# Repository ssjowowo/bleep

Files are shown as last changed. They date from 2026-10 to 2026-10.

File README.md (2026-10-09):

# Bleep

**A DIY touchscreen universal remote.** It's built around an ESP32-S3 on a main board of our own, with a 3.5″ IPS touch display, 14 physical keys, IR send and learn, haptics, and Home Assistant control over Wi-Fi. The case is 3D-printed and only 13 mm thick.

<p align="center">
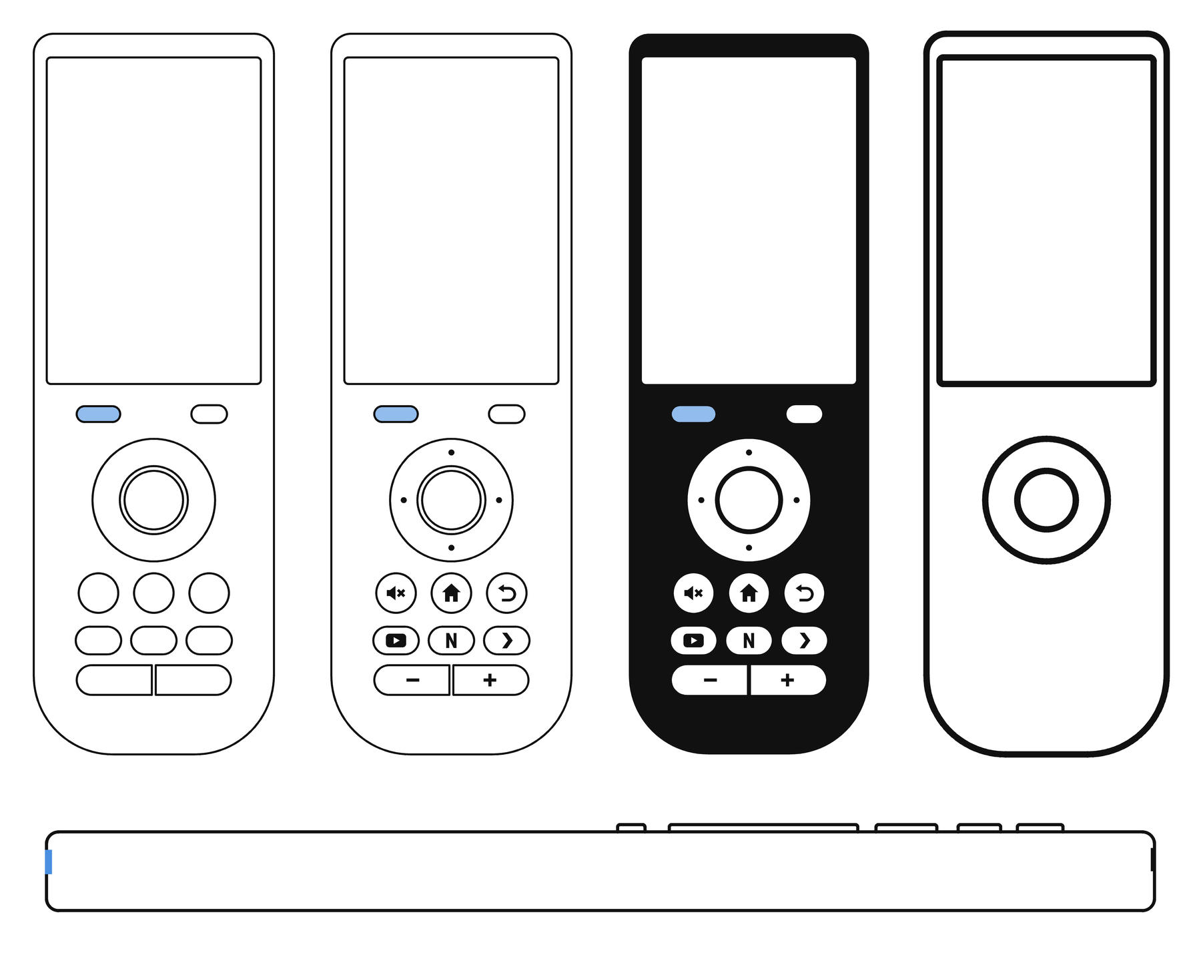
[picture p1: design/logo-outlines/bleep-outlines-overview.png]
Bleep front outlines in four styles and a side profile
  
  &nbsp;
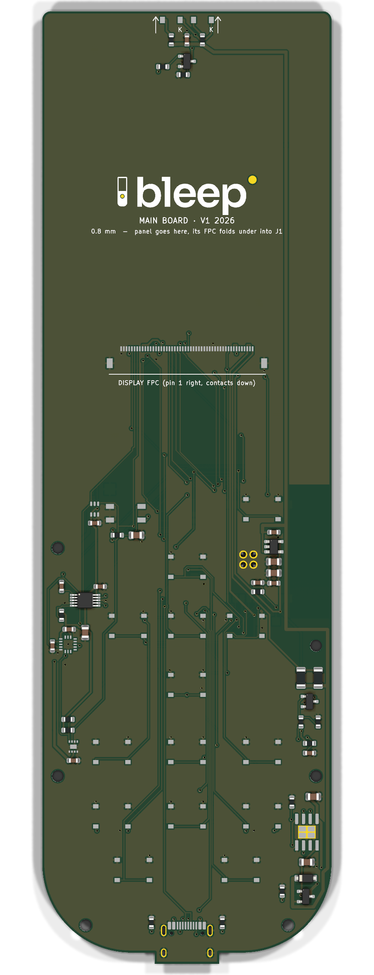
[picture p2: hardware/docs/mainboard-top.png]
Render of the Bleep v1 main board, top side
  
</p>

## What it is

Most universal remotes either have a screen and few buttons, or lots of buttons and no screen. Bleep has both. The touchscreen shows activities, now-playing and smart-home controls. The keys you use without looking stay physical: a D-pad ring with OK, Back, Home, Mute, three app keys (YouTube, Netflix, Plex) and a volume rocker.

- **IR out**: two side-view 940 nm IR LEDs at the top end control TVs, receivers and boxes.
- **IR learning**: a 38 kHz receiver behind a small window under the screen copies codes from your old remotes.
- **Wi-Fi**: Home Assistant control of lights, scenes and media through the ESP32-S3.
- **Feel**: a coin vibration motor driven by a DRV2605L haptics driver.
- **Smart power**: lift-to-wake (accelerometer), wake on touch or any key, auto-brightness (light sensor), and a fuel gauge for an accurate battery percentage. Asleep it draws about 0.1–0.15 mA, so a charge lasts months.
- **USB-C** for charging and flashing.

The hardware is designed for all of this. The firmware's app and UI run today in an emulator (on the PC or in a browser) while the boards are being made; the ESP32-S3 port comes when they arrive. See [firmware/README.md](firmware/README.md).

The industrial design comes from a concept pack made in Claude Design (design **1b "Pebble"**, in `design/`). The brand (wordmark, logo lockup) comes from the Bleep brand book.

## Status

| Part | State |
|---|---|
| Main board v1 | **Ordered** from JLCPCB on 2026-10-08 (5 boards, 2 assembled). The design is locked: the files in `hardware/mainboard/` are the ones in production. |
| Enclosure | Ready to print. The back plate is flat, with room for a 4.0 × 50 × 85 mm Li-Po (405085) under the screen. |
| Display | BuyDisplay ER-TFT035IPS-6 + capacitive touch, **ordered** 2026-10-09. Its cable fold gets checked on the real panel before assembly. |
| Battery | **Ordered** 2026-10-09 (405085 planned; if the cell differs, set `BATT` in `layout.py` and rebuild the back plate). |
| Firmware | App and UI (C + LVGL 9) running in a PC/browser emulator with 32 scripted test scenarios; ESP-IDF port next. [firmware/](firmware/) |

## Hardware at a glance

| | |
|---|---|
| Size | 60.7 × 182.2 × 13.0 mm |
| MCU | ESP32-S3-WROOM-1-N8R2 (8 MB flash, 2 MB PSRAM), antenna at the right edge beside the D-pad |
| Display | 3.5″ IPS 320 × 480, ILI9488 on an 8-bit parallel bus (much faster than SPI), FT6236 capacitive touch |
| Keys | 14 tactile switches, each on its own wake-capable GPIO |
| IR | 2 × VSMB2948SL LEDs (≈ 125 mA peaks), IRM-H638T receiver for learning |
| Sensors | MMA8452Q accelerometer, LTR-303ALS light sensor, MAX17048 fuel gauge |
| Power | 1-cell Li-Po, TP4056 charger with load sharing, ME6211 3.3 V LDO |
| Board | 2 layers, 0.8 mm, 54 × 178 mm. JLCPCB assembles the top side; you solder the ESP32 module, battery and motor on the underside. |
| Case | PETG, two colours for the key labels (flush inlays), plus translucent blue PETG for the IR and sensor windows (two small separate prints); the board screwed to the front shell (4 × M2×4) and the back plate held by 2 × M2×8 and two snap fingers, all into heat-set inserts |

The parts list, pin map, assembly steps, ordering guide (≈ €130 in total, delivered to Cyprus) and firmware notes are in **[hardware/README.md](hardware/README.md)**.

## How it's built

Everything mechanical comes from one file, [`hardware/layout.py`](hardware/layout.py). It holds the display and part sizes, the key layout, where each part sits, the z stack and the screw points, and it runs fit checks on all of them. Two generators read it:

- **Enclosure**: `layout.py` writes `enclosure/params.scad`, and [`enclosure/remote.scad`](hardware/enclosure/remote.scad) (OpenSCAD) builds the front shell, its two windows, back plate, key caps and label inlays as STLs, plus interference checks.
- **Main board**: [`mainboard/gen_mainboard.py`](hardware/mainboard/gen_mainboard.py) places the parts in KiCad 10 from the same numbers. [Freerouting](https://github.com/freerouting/freerouting) routes it, then the generator adds ground pours, runs DRC and exports Gerbers, BOM and CPL for JLCPCB.

The board and the case can't drift apart. Since the board was ordered, `layout.py` checks every value the board was built from against `mainboard/pcb_lock.json`. It refuses to run if a case change would move one of them.

## Repository layout

```
design/              concept pack (open the .dc.html files in a browser), brand assets, outline drawings
hardware/
  layout.py          the single source of truth for the mechanics
  build.sh           rebuilds everything from layout.py
  enclosure/         OpenSCAD source and the printable STLs (enclosure/stl/)
  mainboard/         KiCad board, generator, routing logs; fab/ = Gerbers, BOM, CPL (locked)
  viewer/            3D colour viewer (three.js) for trying colourways
  docs/              datasheets and renders
HANDOFF.md           current working state, for picking the project up on another machine
```

## Building

```bash
cd hardware
./build.sh enclosure   # STLs, renders and fit checks
./build.sh viewer      # meshes for the 3D viewer (viewer/index.html)
```

You need Python 3 (no extra packages) and OpenSCAD 2021.01 or newer, on the PATH or set with `OPENSCAD=`. The board rebuild (`./build.sh pcb`) also needs KiCad 10 and Freerouting, and it's disabled while v1 is locked.

To open the 3D viewer locally, run `python3 -m http.server -d hardware/viewer 8742` and go to <http://localhost:8742>.

## Roadmap

1. Boards and display arrive: check the display cable fold, solder the underside parts, print the case.
2. Firmware: LVGL UI (activities, now playing, Home Assistant), IR send and learning through the RMT peripheral, deep sleep with key, touch and lift wake.
3. Fixes found on the real hardware go into a v2 board.

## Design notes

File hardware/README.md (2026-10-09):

# Bleep v1 — hardware (own ESP32 + plug-in display)

**One main board of our own** with a **3.5" IPS panel with capacitive touch (BuyDisplay ER-TFT035IPS-6)** lying flat on it, plugged into a connector on the board. The keypad has a ring D-pad. The shell is slim: only wall and clearance beside the glass, the glass 4.8 mm from the top end (5 mm top corners), and the power key and sensor window in a row under the screen.

| | |
|---|---|
| Size | 60.7 × 182.2 × **13.0 mm** |
| Display | BuyDisplay ER-TFT035IPS-6 (ILI9488) + ER-TPC035-6 touch (FT6236), 3.75 mm, one 50-pin FPC |
| ESP32 | ESP32-S3-WROOM-1-N8R2 module (8 MB flash, 2 MB PSRAM) |
| Battery | flat Li-Po up to 4.0 mm thick and 50.8 × 86.1 mm (sized for a 405085), under the screen |
| You solder | ESP32 module, battery, vibration motor (the display just plugs in) |

Everything is generated from [`layout.py`](layout.py):

```bash
./build.sh            # everything: STLs, renders, PCB, viewer meshes
./build.sh enclosure  # STLs + renders + fit checks
./build.sh pcb        # main board: place, route, DRC, Gerbers, BOM/CPL
```

It needs Python 3 (no extra packages) and OpenSCAD 2021.01+, found on the PATH or set with `OPENSCAD=`. The PNG renders in `docs/` need a display, so on a headless Linux box they're skipped.

## Stack (from the back face, 4 mm cell)

| z (mm) | |
|---|---|
| 0 – 1.5 | back plate |
| 1.5 – 6.0 | open space: battery (+0.5 swell gap) under the screen; ESP32 module, vibration motor and the heads of the 4 board screws under the keys. The back plate is flat; the board rests on rails along its edges under the screen, a standoff at each of the plate's 2 screws and a 3 mm pillar under each key switch |
| 6.0 – 6.8 | main board, 0.8 mm |
| 6.8 – 8.4 | under the LCD: the 50-pin ZIF connector (1.5 mm), the folded display FPC and its parts area, foam pads at the top end |
| 8.4 – 12.15 | LCD (2.1) + touch glass (1.65) |
| 12.15 – 12.95 | front frame over the glass edge |

The cell thickness sets H: 3 mm → 12.0, 4 mm → 13.0, 5 mm → 14.0 mm. Change `BATT` in `layout.py` and rebuild.

## Main board

> **Locked (2026-10-08).** Bleep v1's main board is ordered from JLCPCB: 5 boards, green mask, HASL, Economic assembly of 2. `mainboard/mainboard.kicad_pcb` and `mainboard/fab/` are the ordered files and are read-only. `./build.sh` no longer touches the board, and `./build.sh pcb` refuses. Only the shell and the firmware change from here. `layout.py` stops with "PCB LOCKED" if a shell change would move anything the board was built from: part positions, keys, holes, outline, antenna keep-out, GPIO map. The record is in `mainboard/pcb_lock.json`.

Status (2026-10-08, slim version, after an independent review): fully routed, KiCad DRC **0 violations, 0 unconnected**; Gerbers, BOM and CPL in `mainboard/fab/`. The CPL rotations are checked against JLCPCB's own footprints for every part. Renders: [top](docs/mainboard-top.png), [underside](docs/mainboard-bottom.png).

Branding follows the Bleep Brand Book (PCB section): the logo lockup in one-colour silk, large on the back (40 mm, under the battery) and smaller on the front (26 mm, under the panel), each with the board ID `MAIN BOARD · V1 2026`. The display and the ring round the LED are knocked out of the silk, and both LED dots are bare copper pads. They come out gold with ENIG; with the HASL finish in the current order they're silver tin. The brand book also calls for a matte black solder mask; colour and finish are order options, not changes to the files. The lockup is built in `mainboard/logo.py` from the brand book's mark and a trace of the wordmark (`../design/brand/`); `gen_mainboard.py rebrand` re-applies it to the routed board without re-routing.

Routing: [Freerouting](https://github.com/freerouting/freerouting) 2.5 does it, about 5 minutes for `./build.sh pcb`. A few things are drawn by hand first and passed to it as fixed copper: the VSYS rail (charger → right edge → LDO → up the right side to the IR LEDs), the LDO's pins and the 3V3 run to the module, the vibration-motor wires (on the bottom layer) and the USB D+/D− crossing. VBAT and VSYS are 0.5–0.6 mm wide (the cell → LDO path carries the Wi-Fi bursts: ≈ 0.2 Ω end to end, about 0.1 V at 500 mA), the other power nets 0.3 mm, and Freerouting may not put vias in SMD pads. GND is a pour on both layers; after routing, `gen_mainboard.py fab` stitches any pour piece the tracks cut off back to the main ground with a via. Freerouting needs a Java 25 runtime; `build.sh` looks for it and the jar in `%LOCALAPPDATA%\freerouting\`, and its settings file (`%APPDATA%\freerouting\freerouting.json`) has automatic neck-down off, so no track goes below 0.15 mm. The older grid router (`mainboard/route.py`) is still there but couldn't route this layout.

| Part | Where | Notes |
|---|---|---|
| 14 key switches (TS-1187A) | top, JLCPCB | each straight to an ESP32 RTC GPIO, so any key wakes it |
| USB-C | top, bottom edge | 5.1 k CC pull-downs, D+/D− to the ESP32's native USB (flashing + serial) |
| TP4056 charger | top, right strip, near USB-C | 360 mA (PROG 3.3 k); CHRG/STDBY to GPIO12/3 |
| Load sharing (AO3401A + B5819W + 100 k) | top, under the charger | on USB the remote runs from VBUS and the charger sees only the cell, so it terminates properly; off USB the cell feeds the system through the P-MOSFET |
| ME6211 3.3 V LDO | top, over the module by its 3V3 pin | 500 mA, from VSYS (the cell, or USB when plugged in) |
| DRV2605L + MMA8452Q | top, left strip | haptics (always enabled, standby over I²C); accelerometer for lift-to-wake (INT1 → GPIO2, transient/motion interrupt) |
| 2 × VSMB2948SL IR LEDs | top edge, centred; their driver sits under the LCD | 22 Ω each from VSYS (≈ 125 mA peaks at 4.2 V), one AO3400A; silk arrows mark the lens direction |
| Backlight driver | top, right strip | LED+ from VSYS via 2 × 22 Ω (1206, they see up to ≈ 0.12 W each on USB), cathodes switched by an AO3400A on GPIO46 (PWM) |
| 50-pin 0.5 mm ZIF connector (XUNPU FPC-05F-50PH15) | top, under the panel, JLCPCB | bottom contact, flip lid; the display FPC folds under and plugs in |
| ESP32-S3-WROOM-1-N8R2 | **underside**, across the board just below the screen | **you solder**. It must be the **N8R2**: the N8R8 (octal PSRAM) uses GPIO35–37, which are LCD D0–D2 here; antenna at the **right edge**, beside the D-pad, with no copper on either layer around it (3.5 mm past the module's sides). It can't go under the screen: the panel would detune it. |
| IR receiver (Everlight IRM-H638T, 38 kHz) | in the row under the screen, left, under the sensor window (3.0 mm hole) | for **learning** codes from existing remotes; output on GPIO42. Powered from GPIO1 through 220 Ω + 10 µF, so it's only on while learning (it draws 0.4 mA) |
| Ambient light sensor (LTR-303ALS-01) | beside the IR receiver, same window (1.6 mm hole, with a translucent PETG light pipe down to it) | auto-brightness; I²C `0x29` |
| Fuel gauge (MAX17048) | top, left strip | battery %, time-to-empty and the cell voltage; I²C `0x36` |
| EN + GND reset pads | underside, below the module, under a slot in the back plate | short them (a small screwdriver across both) to reset the ESP32 without opening the case |
| BAT+ / BAT− pads, vibration-motor pads | underside: battery pads just below the screen on the left, motor in the left strip | the motor is an 8 mm ERM (or LRA) coin, set in firmware |

### ESP32-S3 pin map

| GPIO | Use | GPIO | Use |
|---|---|---|---|
| 0 | OK key (hold at reset = download mode) | 21 | LCD D/C |
| 1 | IR receiver power (high while learning) | 35 – 41 | LCD D0 – D6 |
| 2 | MMA8452Q INT1 (lift-to-wake) | 42 | IR receiver output (learning) |
| 3 | charger STDBY | 43 | LCD D7 |
| 4, 5, 6, 7 | UP, RIGHT, LEFT, DOWN | 44 | LCD WR |
| 8, 9 | NFLX, YT | 45 | IR LED (pulled low) |
| 10, 11 | VOL+, VOL− | 46 | backlight PWM (pulled low) |
| 12 | charger CHRG | 47, 48 | I²C SDA / SCL |
| 13, 14 | PWR key / touch INT | 19, 20 | USB D− / D+ |
| 15, 16, 17, 18 | BACK, HOME, MUTE, PLEX | | |

I²C: FT6236 touch `0x38`, DRV2605L `0x5A`, MMA8452Q `0x1C`, LTR-303ALS `0x29`, MAX17048 `0x36`. The LCD and touch controller share an RC power-on reset (10 k × 1 µF), so after power-up the firmware resets the ILI9488 with its software-reset command (0x01). Display: ILI9488 on the ESP32-S3's i80 LCD bus, **8080 8-bit parallel** (IM2–IM0 = 011, CS tied low, RD tied high), 320 × 480. That's several times faster than the ILI9488's SPI mode, which only takes 18-bit colour. GPIO43/44 are UART0, so use the USB-Serial/JTAG console in firmware; the ROM's boot messages on GPIO43 are harmless because WR stays high. Every GPIO is used.

## Display

**BuyDisplay ER-TFT035IPS-6** — 3.5" IPS, 320 × 480, ILI9488, LCD 54.56 × 82.84 × 2.1 mm — with the **ER-TPC035-6** capacitive touch panel (FT6236, glass 56.54 × 84.96 mm, 3.75 mm in total). Backlight ≈ 3.0–3.3 V at 120 mA. One 50-pin 0.5 mm FPC, 30 mm long, carries the LCD and the touch I²C. The datasheet, touch drawing and connector drawing are in `docs/`; the old QD3525 papers are in `docs/old-qd3525/`.

The FPC leaves the panel's bottom edge, makes a U-bend down past the glass and runs 24 mm back under the LCD into the ZIF connector J1. That puts the FPC's pin 1 on the right, seen from the front; the board's silk says so. The FPC's small parts area (≤ 1.5 mm) also lies under the LCD.

## Assembly order

1. **ESP32 module** (underside, lying across the board below the screen, antenna end at the right edge as the silk shows): tack two corners, then solder the edge pads. Solder the centre GND pad from the top side: feed solder into its four 1 mm holes until each one fills (the module's pad heats slowly, so use a hot, broad tip). Pins 1 and 40 (GND, by the antenna) are also tied to that pad with tracks.
2. **Battery** leads to BAT+ / BAT− (underside, just below the screen on the left), **motor** leads to its pads (red to +). Cut the battery's plug off and solder the leads straight to the pads, red to BAT+: at 4 mm there's no room for a connector. Stick the motor to the board's underside by its adhesive back, on its spot in the left strip. The cell goes at the top end, under the screen and as far from the antenna as it goes, between the four corner guides on the back plate; its leads run down to the pads. A piece of Kapton tape on the board's underside over the cell area keeps via tips off the pouch.
3. **Display**: lay the panel face down beyond the board's key end, FPC towards J1. Flip J1's lid up, slide the FPC in with its contacts facing the board, then close the lid. Fold the panel over onto foam pads (two layers of 1 mm foam tape) at the board's top end, so the FPC makes a U-bend under it. Stick the pads left and right of the small IR-driver parts there (they sit under the LCD now), not on them.
4. Flash over USB-C. esptool resets the ESP32 into download mode over USB by itself. If a broken firmware stops that from working, hold OK and short the two reset pads through the slot in the back plate (a small flat screwdriver across both), then release them while still holding OK. Plugging in USB doesn't reset the ESP32 once the battery is connected.
5. Key caps into the front shell, face down: the **OK** button first, then the one-piece **D-pad ring** over it (the ring holds the OK in), then the other caps.
6. Board into the front shell (glass into its pocket), then screw it to the four posts in the key area with **4 × M2×4** from its underside, into the inserts. Use nylon screws, or at least put a disc of Kapton tape under the head at the top-left hole (H1): a VBAT track passes 1.75 mm from its centre on the underside, under the edge of a 4 mm head, with only solder mask in between.
7. Battery on the back plate between its corner guides. Hook the back plate's top end in first: its two snap fingers click into grooves in the top wall. Then close it with **2 × M2×8** through the bottom bosses (they pass through the board too).

## Ordering

Prices checked 2026-10-07, delivered to Cyprus. Every AliExpress line adds about €3 of EU import charges.

### 1. JLCPCB: PCB + assembly, plus LCSC in the same parcel

Before paying, open J1 in the Component Placements 3D view: its flip lid and opening must face the bottom of the board (towards the keys), where the folded cable comes from. Upload `mainboard/fab/mainboard-gerbers.zip`, then PCB Assembly with `mainboard-BOM.csv` and `mainboard-CPL.csv`. PCB: 2 layers, **0.8 mm**, HASL, qty 5. Assembly: **Economic**, top side, qty 2. Order remark for the IR LEDs: *"D1/D2 VSMB2948SL side-view IR LEDs: lens faces the board's top edge (silk arrows), cathode = pad marked K."*

| JLCPCB item | US$ |
|---|---|
| 5 PCBs, 2 layers, 0.8 mm, 54 × 178 mm | ≈ 9.40 |
| Economic assembly setup + stencil | ≈ 9.71 |
| 10 Extended parts × $3.07 (USB-C, TP4056, ME6211, DRV2605L, MMA8452Q, IR LED, ZIF connector, IR receiver, light sensor, fuel gauge) | 30.70 |
| Parts for 2 boards (DRV2605L $1.58, MMA8452Q $1.57, MAX17048 $1.31, IR LED $0.45, LTR-303ALS $0.27, ZIF $0.21, IR receiver $0.13, TP4056 $0.18, AO3400A $0.09, USB-C $0.07, ME6211 $0.06, switches $0.02 …) | ≈ 15.00 |
| Solder joints | ≈ 1.20 |
| **JLCPCB subtotal** | **≈ 66** |

Then at [LCSC](https://www.lcsc.com/) add these and choose "Combine your LCSC and JLCPCB orders" at checkout (one parcel, one shipping fee):

| Part | LCSC | Qty | US$ |
|---|---|---|---|
| ESP32-S3-WROOM-1-N8R2 | [C2913204](https://www.lcsc.com/product-detail/C2913204.html) | 2 (one spare) | 9.36 |
| M2 × 3 × 3.2 brass heat-set insert | [C51938982](https://www.lcsc.com/product-detail/C51938982.html) | 50 (minimum) | 0.50 |

Shipping ≈ $11 (Global Standard, 12–19 days). VAT is added at checkout.

### 2. BuyDisplay: the display

[3.5" IPS 320×480 TFT with capacitive touch](https://www.buydisplay.com/3-5-inch-ips-320x480-tft-lcd-display-capacitive-touch-screen) (ER-TFT035IPS-6). Options:

- **"3.5" Capacitive Touch Panel with Controller"** (+$5.57)

≈ US$15.20 + ≈ $10 shipping. Expect Cyprus VAT (19 %) and maybe a courier handling fee on delivery. The price and options come from an archived copy of the page (the live site has a bot check), so confirm them at checkout.

### 3. AliExpress (Ship to: Cyprus)

| Part | Listing | Variant | € |
|---|---|---|---|
| 8 mm coin vibration motor, ERM 0827, 5 pcs | [1005007600971536](https://www.aliexpress.com/item/1005007600971536.html) | "8x2.7mm" | 2.24 |
| M2 × 8 pan-head screws, 100 pcs | [1005005581270091](https://www.aliexpress.com/item/1005005581270091.html) | "M2 100pcs" + "8mm" | 2.99 |
| M2 × 4 nylon pan-head screws (the board screws) | search "M2 nylon screw 4mm" | 4 mm | ≈ 1–2 |
| 1 mm double-sided foam tape, 10 m | [1005007483857645](https://www.aliexpress.com/item/1005007483857645.html) | 10 mm wide | 3.53 |

Alternative screws: [4000970993800](https://www.aliexpress.com/item/4000970993800.html) (€2.26, 50 pcs stainless). An LRA 0832 exists ([1005010354264566](https://www.aliexpress.com/item/1005010354264566.html)) but costs ≈ €23.6 with shipping; the ERM works with the DRV2605L (a firmware setting).

### 4. Battery: Eremit, to the German forwarding address

Li-Po cells count as dangerous goods for shipping, and the shops that sell them won't send them to Cyprus directly. Eremit ships only within Germany but explicitly allows forwarding services, so order to the forwarder's German address.

Look for a flat Li-Po (pouch) cell, **at most 4.0 mm thick and 50.8 × 86.1 mm**, with its leads on a short edge and a protection circuit. Pouch cells are named by size: thickness in tenths of a mm, then width, then length, so **405085** is 4.0 × 50 × 85 mm, the largest that fits and the one the back plate is set up for. 3.0–4.0 mm thick, up to 50 mm wide and 86 mm long all fit: 405085, 405080, 404080, 405060 or the smaller 404060. Set `BATT` in `layout.py` to the cell you buy and rebuild the back plate, so its corner guides fit it. Not yet chosen.

### Rough total

| | € |
|---|---|
| JLCPCB + LCSC + shipping (≈ US$86) | ≈ 74 + VAT |
| BuyDisplay panel + touch + shipping (≈ US$25) | ≈ 22 + VAT |
| AliExpress (3 lines) + ≈ €9 import charges | ≈ 17.80 |
| Batteries (to Germany, not yet chosen) | ≈ 15–20 + forwarding |
| **Total** | **≈ €130 + forwarding + VAT on the JLCPCB and BuyDisplay parts** |

Already on hand (not counted): PETG in two colours, solder, flux, solder wick. The second colour prints the key labels and the ring dots.

**Windows.** The IR window and the sensor window are two small separate prints in translucent PETG (Creality CR-PETG Translucent Blue), fitted by hand with a drop of clear glue:

- `stl/ir_window.stl` (15.8 × 6.2 × 1.8 mm, printed flange down): a plug that fills the slot in the top wall, flush outside. Push it in from the inside before the board goes in; its flange sits in the recess round the slot, so it can't be pushed out.
- `stl/sensor_window.stl` (10.8 × 3.8 mm, pegs 4.95 mm tall, printed pill face down): the pill sits flush in its recess under the screen, with a peg down through each hole. The peg over the light sensor runs on to 0.5 mm above it as a light pipe, because through the bare 1.6 mm hole the sensor would see only about ±8°.

Each has 0.1 mm clearance per side for a press fit; if a peg is too tight, run a 1.5 / 3.0 mm drill through the shell's holes. Print a few spares: they're tiny.

Before printing the real ones, check the filament passes infrared. Print a 1 mm square, hold it over a working remote's LED and work your TV from across the room (a phone's front camera usually shows the LED's glow through it too). Clear and translucent dyed PETG normally pass 940 nm. The blue tint dims and colours what the light sensor sees, so its lux reading needs a scale factor in firmware; calibrate it once against a phone's light meter. Auto-brightness only needs it to rise and fall with the room.

## The display cable fold

The board is designed from BuyDisplay's drawings, and the cable fold is the one thing the drawings can't settle. The cable leaves the panel through two narrow, flexible necks only 3.9 mm long. After them comes a 48 mm wide section, centred about 2.4 mm towards pin 1 (right), with a strip of parts 4.9–7.0 mm out from the glass edge. How much cable the real fold uses can't be predicted to better than about ±1.5 mm. So the design has slack:

- J1 sits 1.6 mm closer to the fold than the nominal fold needs. A looser fold still reaches fully into J1. A tighter one bottoms out in J1, and the extra cable makes the fold bulge outward by about half of it.
- The enclosure model uses the full 48 mm width for the fold, already bulged, and keeps it clear of the power key, the IR receiver, the UP switch and the antenna.

Ordering the display and the boards together is fine. When the display arrives, check the fold before assembling: lay the panel face down beyond the key end, fold the cable under as it will sit, and hold the panel in place. The cable end should slide fully into J1, and the fold shouldn't stick out more than about 2 mm past the glass edge. If either is off, the fix goes in the 3D-printed front shell, not the board: the glass pocket moves by up to about ±1 mm towards or away from the fold, and you reprint the front shell. Ask me for that change. `LENS_Y0` in `layout.py` also positions J1, so it has to be done with J1 pinned to where it is on the boards you have.

## Firmware notes

- IR: send with a 33 % carrier duty (the LEDs see ≈ 125 mA peaks).
- Backlight: it's fed from VSYS through 11 Ω. On battery it dims as the cell drains (≈ 100 mA at 4.2 V, much less near 3.4 V), so scale the PWM duty with the measured battery voltage. On USB, VSYS is ≈ 4.6 V and full duty would be ≈ 135 mA, above the panel's 120 mA rating. Cap the duty at about 85 % while USB is present, which is when CHRG (GPIO12) or STDBY (GPIO3) reads low.
- Charger status: CHRG (GPIO12) and STDBY (GPIO3) are open-drain and have no pull-ups on the board, so enable the ESP32's internal pull-ups on both. Both are RTC GPIOs, so use `rtc_gpio_pullup_en()` for them in deep sleep. Read them as:
  - CHRG low = charging
  - STDBY low = full
  - both high = no USB
- Lift-to-wake: ignore MMA8452Q interrupts while the vibration motor runs; it's ~7 mm away.
- IR learning: drive GPIO1 high to power the receiver and wait about 100 ms for it to settle, then capture GPIO42 with the RMT peripheral in receive mode (the output is active-low and demodulated). Turn the IR LEDs off while learning. Afterwards drive GPIO1 low and keep GPIO42's pull-up off, so nothing powers the receiver through its output; hold GPIO1 low in deep sleep (`rtc_gpio_hold_en()`).
- Light sensor: it looks out through a 1.6 mm hole about 5 mm above it, so treat its readings as relative and calibrate the brightness curve by eye.
- Fuel gauge: read SOC (register 0x04), CRATE and VCELL (0x02, the cell voltage, also used for the backlight scaling); it runs straight off the cell and needs no setup beyond an optional quick-start. Let it hibernate in standby (≈ 4 µA instead of 23 µA).
- Standby budget: with the IR receiver off, the board draws roughly 0.1–0.15 mA asleep (the ESP32 in deep sleep, the LDO's 40 µA, the touch controller in monitor mode, the accelerometer and the fuel gauge), so a 1000 mAh cell lasts several months.
- Touch sleep: the FT6236's reset is on the RC power-on reset, not a GPIO, and it only leaves hibernate through a reset. So never send it to hibernate; use its monitor mode, which wake-on-touch (GPIO14) needs anyway.
- Haptics and Wi-Fi share the 3.3 V regulator (500 mA). A Wi-Fi transmit burst (≈ 350 mA) plus the motor (up to ≈ 100 mA) is close to its limit on a nearly empty cell, so keep haptic pulses short and fire them just after the Home Assistant request has gone out, not during it.
- Near an empty cell (≈ 3.4 V) the backlight has almost no headroom over the LEDs' 3.0–3.2 V and gets very dim; that's expected.

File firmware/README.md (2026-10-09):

# Bleep firmware

The spec is [REQUIREMENTS.md](REQUIREMENTS.md). Right now the firmware runs in a **PC emulator**. The ESP32-S3 build comes once the board arrives.

## Layout

| Path | What |
|---|---|
| `hal/hal.h` | Hardware interface: keys, backlight, LCD sleep, haptics, radio links (Wi-Fi, directed Bluetooth), IR start/stop and Bluetooth key down/up, battery, light sensor, deep sleep with a wake mask, wake cause, RTC memory, PSRAM buffers |
| `app/` | Hardware-independent firmware: devices, activities and routines (`model.c`, factory defaults), key routing and activity sequences (`control.c`), running routines (`routine.c`), radio policy (`radio.c`), power states (`power.c`), firmware updates (`update.c`), and the interfaces for the saved setup (`config.h`) and Home Assistant (`ha.h`) |
| `app/ui/` | LVGL 9 UI from the "Bleep Remote UI" design (2c Flat): tabs, pages, HA cards, keyboard, overlays |
| `app/ui/fonts/` | Figtree, icon and logo fonts, generated (see below) |
| `sim/` | PC emulator: SDL window and control panel, browser build (`web.c`, `web/index.html`), headless script runner |
| `sim/demo.c` | The demo house (Wi-Fi "Home-5G", HA user Sam, 7 devices, 6 activities, 3 routines): what the emulator's flash holds before anything is saved. |
| `sim/store.c` | The emulator's flash: the saved setup and the secret store. The browser's localStorage in the web build; `--store FILE` (and `FILE.secrets`) natively; memory only without it. |
| `sim/ha_mock.c` | A demo Home Assistant. Its house appears once the remote has signed in. The remote will use a WebSocket client with the same interface. |
| `sim/ir_library_demo.c` | Stand-in IR library with made-up codes. The remote will use the curated Flipper-IRDB subset. |
| `tools/` | Font and icon generators |

Everything in `app/`, `app/ui/` and `hal/hal.h` goes into the remote's firmware unchanged. Test and demo data lives only in `sim/`: `hal_sim.c` stands in for the hardware, and `demo.c`, `ha_mock.c` and `ir_library_demo.c` stand in for the saved setup, Home Assistant and the IR library. The app itself starts from factory defaults: no Wi-Fi, signed out, no devices.

What you change in the emulator is saved the same way the remote saves it (JSON, `app/config.c`): in the browser it survives a reload, natively with `bleep_sim --store FILE`. To start as a new remote, with nothing set up: `bleep_sim --factory`, the browser page with `?factory` (e.g. `http://localhost:8080/?factory`), or a test script whose first command is `factory`. `?demo` forgets what the browser saved and starts over with the demo house.

## Run the emulator in a browser

Works on a headless machine. Only Docker is needed, or a local emsdk if you have one:

```sh
firmware/sim/serve.sh          # builds to build/web, serves on port 8080
```

Open `http://<this machine>:8080/` from any browser on the network. Over VS Code Remote, the port is forwarded automatically; see the Ports panel.

The page has the screen on the left (1×, 1.5× or 2×) and the physical keys, sensors, live state and event log on the right. The PC keyboard shortcuts below work there too, and touch works on a phone or tablet.

It is the same firmware compiled to WebAssembly with Emscripten. The first build fetches LVGL and takes a minute or two.

## Run the emulator in a desktop window

Install the build tools once:

```sh
sudo apt install build-essential cmake ninja-build pkg-config libsdl2-dev
```

Build and run from the repo root:

```sh
cmake -S firmware/sim -B build/sim -G Ninja
cmake --build build/sim
./build/sim/bleep_sim            # add --zoom 2 for a bigger remote
```

The first configure downloads LVGL v9.6.0.

Two windows open:

- **Bleep**: the 320×480 screen. The mouse is your finger. Click to tap, drag to scroll, and hold to long-press. Holding an activity tile edits it.
- **Bleep · controls**: the 14 physical keys and a pick-up button. It also has the battery, USB and light-sensor controls, switches for whether the router and the TVs answer (to see links fail and retry), "Idle +10 s / +2 min" to jump to dim, screen-off and deep sleep, the live power and radio state, and the event log, which shows every IR and BLE send.

Keyboard shortcuts in the Bleep window:

| Key | Remote key |
|---|---|
| arrows | D-pad |
| Enter | OK |
| Esc or Backspace | BACK |
| H | HOME |
| P | PWR |
| + / − (or PgUp / PgDn) | VOL |
| M | MUTE |
| N | NFLX |
| Y | YT |
| X | PLEX |
| L | pick up |

While a text box is open, typing goes into it.

The terminal shows the same log with timestamps.

## What it emulates

- **Activities**: starting one runs its power and input sequence and switches the radios. Shield TV's Now playing comes from HA. All off switches every device off. PWR ends the running activity. You can also create, edit and delete activities.
- **Devices**: per-device pages with inputs, keypad, controls and greyed-out keys. Add a device by:
  - Bluetooth pairing (completes after about 4 s, as if the TV accepted)
  - picking from the IR library (test, then the next code set)
  - learning IR (each key is "received" after 1.5 s)
  - picking a Home Assistant media player

  You can also rename, change the type, forget Bluetooth, or delete.
- **Keys**: go to the active target, which is the last thing you chose. Opening a device from the Devices tab selects it on every screen. Starting or tapping an activity hands the keys to the activity. The status bar pill shows the active target, and tapping it goes back there. With nothing active, a key gives a "no" buzz and a hint.
- **Home**: six rooms with a card for every HA domain in the design. Service calls change state the way HA would. The alarm code is 1234.
- **Radio policy**: Wi-Fi only on the Home tab, with 20 s linger, or while an HA device or the Now playing source needs it. BLE follows the running activity and stays up while warm. IR is ready only for IR devices. The receiver is on only while learning.
- **Power**: Active → Dim (lock/ambient screen) after 8 s → screen off after the "Sleep after" setting → deep sleep 2 min later. On the remote a wake from deep sleep is a reboot, and the emulator reboots too: the SDL build starts itself again and the browser page reloads (its log carries on). Only what the remote keeps in RTC memory survives (`app/retained.c`): what's running, which devices are on, the page, and each key's code, so a key that wakes it goes out over IR before the app is up. A touch or pick-up wake shows the Wake screen. A key held down while it sleeps can't wake it, and three pick-ups in a row that come to nothing turn lift-to-wake off until a key wakes it. On USB the charging screen stays up.
- **Held keys**: IR repeats while a key is held (the log shows the repeat frames at the release), Bluetooth sends key down and key up, and Home Assistant volume and D-pad repeat every 250 ms.
- **Battery**: the low-battery sheet at 8 %, and battery saver (brightness cap, shorter timeouts, no pick-up wake).
- **Home Assistant sign-in**: Settings > Home Assistant finds two emulated servers ("Home" and "Holiday flat"). "Sign in with your phone" shows a QR code; the emulated phone opens it after 3 s and finishes 4 s later. "Sign in on the remote" accepts `sam` / `correcthorse` (then asks for the two-factor code `123456`) or `alex` / `correcthorse` (no two-factor).
- **Settings**: brightness (auto from the light sensor), haptic strength, idle and sleep timeouts, the HA server, and Dark / Light / Auto theme.
- **Power off**: hold PWR 5 s (the panel's PWR button holds while the mouse button is down; P on the keyboard too), or Settings > Power off. Off, hold PWR 2 s to turn it on; USB while off shows the charging screen. Test scripts use `keydown PWR` / `keyup PWR`.
- **Routines**: Activities tab > Routines. The demo has Movie night (dims the ceiling light through HA, starts Shield TV, presses Home over Bluetooth), Bedtime (ends the activity, lights off) and Louder (receiver volume up × 5). Tap to run with the progress window and Stop; hold to edit, or New routine.
- **Software update**: Settings > Software update checks an emulated bleepremote.com, which offers 0.2.0 (the emulator runs 0.1.0). Install appears only on USB (the panel's USB switch, or `usb on` in a script); unplugging during the 8 s download stops it and changes nothing. When it finishes, the remote restarts to the splash, which now shows 0.2.0. The daily automatic check runs whenever Wi-Fi is already on (the Home tab).
- **Wi-Fi**: Scan finds these emulated networks: Home-5G and Home-2G (password `correcthorse`), Guest (open), Garage (joins but gets no IP address), Shed (too weak, times out) and three neighbours with unknown passwords. Connect saves the credentials only if it works; any other name reports "not in range".

The emulator follows the proposals in REQUIREMENTS.md section 14 where a decision is still open (items 1, 2, 4, 5, 7). Changing a decision means changing `radio.c` or the matching page.

## Tests

```sh
firmware/sim/test.sh            # native
firmware/sim/test.sh --docker   # inside sim/Dockerfile, no local packages needed
firmware/sim/test.sh --wasm     # compiled to WebAssembly like the browser build, run under node
```

The script runs every scenario in `sim/tests/*.txt` headlessly with simulated time. It saves screenshots and logs to `build/sim-shots/`, and each scenario's saved setup to `NAME.store`. A `reboot` in a scenario is a real one (a power cycle): the process ends, and a new one carries on from the next line on the same store, so nothing in memory survives. A wake from deep sleep and a restart after an update end the run the same way, with the RTC block and the wake cause handed over in `NAME.store.state` (`sim/boot.c`). `reach wifi|ble on|off` makes the router or the TVs stop answering. `store FILE` as the first command starts from a given saved file (`sim/tests/fixtures/`). `config_v1` loads a frozen file in today's format: it must keep passing in every later firmware, and the fixture must never be edited to make it pass (rules at the top of `app/config.h`). Scripts tap and click by label text, press keys, change battery and USB, wait, and check text on screen. The commands are listed at the top of `sim/script.c`.

`--wasm` writes to `build/sim-shots-wasm/`. Its screenshots and logs should be byte-for-byte the same as the native run's, which shows the browser emulator runs the same firmware code. One known difference is harmless: LVGL 9.6.0 can log `lv_image_src_get_type: ... invalid magic` when a QR code is deleted (its canvas destructor reads a pointer field as an image header), and whether that appears depends on memory addresses.

## Fonts and icons

`app/ui/fonts/*.c` and `app/ui/icons.h` are generated and checked in:

- `tools/icons.json`: the design's 24 px stroke icons
- `tools/make_icon_font.py`: builds `icons.otf` and `icons.h` (needs `pip install fonttools picosvg`, or the Docker image)
- `tools/gen_fonts.sh`: downloads the UI font (Figtree; change `FAMILY` to switch) from Google Fonts and runs `lv_font_conv` through `npx`

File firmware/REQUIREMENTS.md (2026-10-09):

# Bleep v1 firmware: requirements

Status: draft, 2026-10-09. Not built yet. The hardware facts (pin map, I²C addresses, standby budget, per-chip notes) are in [../hardware/README.md](../hardware/README.md); this file says what the firmware does with them.

The UI design is the Claude Design project "Bleep Remote UI" (`Bleep Remote UI.dc.html`). It hasn't been read into this repo yet, so the screen-level details in section 3 are only what's known so far.

## 1. What it controls

| Target | How | Radio |
|---|---|---|
| Home Assistant | WebSocket API on HA's local `http://` address, signed in with a refresh token (no typed token) | Wi-Fi |
| Google TV / Android TV | Bluetooth LE HID remote (keyboard + consumer control), paired from the TV's *Remotes & Accessories* | BLE |
| TVs, soundbars, other IR gear | 38 kHz IR from the two IR LEDs; codes from a library or learned with the IR receiver | none |

Not in scope: Google's Wi-Fi remote protocol, ESPHome, MQTT.

## 2. Hardware limits the firmware must respect

- No 32 kHz crystal (GPIO15/16 are the BACK and HOME keys), so BLE can't hold a connection through light or deep sleep cheaply. The link drops in deep sleep and reconnects on wake.
- Every GPIO is used. Wake sources are all RTC GPIOs (0–21): the 14 keys, touch INT (GPIO14) and accelerometer INT1 (GPIO2).
- The LCD stays powered in deep sleep (the 3.3 V LDO is always on) and its CS is tied low. Hold WR (GPIO44) high and DC (GPIO21) steady in deep sleep (`gpio_hold_en` + `gpio_deep_sleep_hold_en`) so nothing writes to the panel. Put the ILI9488 into Sleep In before deep sleep; it keeps its frame memory.
- IR receiver: power on GPIO1 only while learning; hold GPIO1 low in deep sleep.
- Wi-Fi bursts and the haptic motor share the 500 mA LDO: fire haptics just after a radio transmit, not during it.
- Backlight is fed from VSYS: scale PWM with VCELL, cap at ~85 % on USB.
- Console over USB-Serial/JTAG (GPIO43/44 are LCD lines).

## 3. UI structure

From the Claude Design project "Bleep Remote UI", style **2c Flat** (locked). Every colour is opaque: no shadows, glow, blur, transparency or gradients, except the fixed colour-wheel and colour-temperature images on the light card. Dark and light themes share token names; Settings picks Dark, Light or Auto (Auto follows the light sensor, with hysteresis). The design file holds the RGB565 token values, the component kit and the LVGL keyboard code.

Bottom tab bar, four tabs:

- **Activities** (first tab): an Activities | Routines switch at the top (routines: section 4), then a 2-column grid of activity tiles (Watch TV, Shield TV, Apple TV, Kodi, Sonos, All off). The running one is highlighted ("Running"). Starting one makes it the active target and opens its page, with the tab bar still showing so you can move between tabs. An activity with a now-playing source opens **Now playing**: artwork, title, progress bar, and one row of subtitles · −10 · play-pause · +30 · audio track (subtitles and audio as small icon buttons at the ends). Any other activity opens an activity page: name, End, which devices get the D-pad and the volume, and the D-pad device's controls, with the volume buttons going to the volume device and Power ending the activity.
- **Devices**: the device manager (section 4). Each device has a page, e.g. an IR TV with HDMI 1–4 inputs and a number keypad.
- **Home**: Home Assistant. Room chips, then entity cards (light with brightness, switches, thermostat, scenes). The design has a card for each HA domain: light (including RGB colour wheel), switch, energy, button, climate, fan, humidifier, water heater, air quality, weather, cover, valve, lock (hold to unlock), alarm (code on the number pad), siren, sensors, camera snapshot, media player, remote, vacuum, lawn mower, scene, script, automation, input helpers, timer, counter, person, sun, calendar, to-do, update and notify.
- **Settings**: battery ring and days left, Brightness (Auto), Wake on pick-up, then three stepped sliders: Haptics (Off / Light / Medium / Strong, buzzes at each step), Idle after (5 s to 1 min, default 8 s) and Sleep after (15 s, 20 s, 30 s, 45 s, 1 min, 1.5 min or 2 min, default 30 s); sleep is kept longer than idle, Wi-Fi (its own page: status, network, password, Scan and Connect. Scan lists the networks in range with signal bars, a padlock on secured ones and "Saved" on the current one; tapping one fills in the name and asks for its password. Edits are a draft: Connect joins the network and waits for an IP address, and only then saves the credentials. On failure it shows why (not in range, wrong password, no IP address, no answer) and keeps the old ones), Home Assistant (status, server found on the network or typed, and sign-in: with a phone through a QR code, or on the remote with username, password and two-factor code; see section 8), Theme.

Screens outside the tabs:

- **Splash** (cold boot only: power-on, reset, firmware update): the Bleep lockup from `design/brand/bleep-pcb-lockup.svg` (off-white body, gold dots) and a Start button. OK also starts; other keys do nothing. A wake from deep sleep is technically a reboot too, but it skips the splash and goes straight to the Wake screen or the active target.

- **Lock / ambient**: large clock and date, a now-playing mini card with play/pause, "Pick up or press any key".
- **Wake**: greeting, a Resume card for the last activity, then three activity shortcuts.
- **Charging**: battery ring and time to full.
- **Low battery**: bottom sheet at about 8 %, with "Battery saver" and "OK".
- **Volume overlay**: shown when the hardware VOL keys are pressed.
- **Keyboard**: one shared `lv_keyboard` (LVGL v9) with four maps: text, name (one capital, then lower case), symbols, and a number pad. It is used for the Wi-Fi password, the HA server URL, device names and alarm codes.

Rendering: ILI9488 in RGB565 (COLMOD 0x55) on the 8-bit 8080 bus, with two 1/10-screen draw buffers in internal RAM and DMA flush. Fonts are Figtree (changed from the design's Sora; the splash logo keeps the brand wordmark), converted to LVGL bitmap fonts with lv_font_conv (11, 12, 14 and 21 px at 4 bpp, plus 44 px and 84 px digits-only at 2 bpp), and an icon font, about 70 KB of flash in all. Hit targets are 44 px or more.

The physical keys act on the **active target**: the last thing chosen, either a device or an activity.

- Selecting a device (opening it from the Devices tab) makes it active on every screen until something else is chosen. A running activity keeps running, but the keys go to the device.
- Starting an activity, or tapping the running one, makes the activity active again.
- The status bar shows the active target as a pill after the clock. Tapping the pill opens that device's page or the activity.
- With nothing active, keys give a "no" buzz and a hint.

The active target is kept in RTC memory, so it survives deep sleep.

## 4. Devices

A device is one thing the remote controls, possibly over more than one transport. Example: "Living room" = a Google TV stick over BLE, plus the TV's volume, mute and power over IR.

Each device stores:

| Field | Content |
|---|---|
| name, icon | shown in the Devices tab and the header |
| transports | any of `ble`, `ir` |
| `ble` | the bonded host's address and keys (from NimBLE's bond store) |
| `ir` | a code set: protocol + code (or raw timings) per function, from the library or learned |
| key map | for each physical key and on-screen button: transport + function, or none |

Default key map for a BLE + IR device: D-pad, OK, BACK, HOME, NFLX, YT, play/pause over BLE; VOL+, VOL−, MUTE, PWR over IR. Each key can be changed.

Devices and activities live in flash (LittleFS, JSON). The running activity's id also lives in RTC memory so a wake needs no flash lookup.

Keys a device doesn't map are greyed out on screen; pressing one gives a short "no" buzz and does nothing.

### Activities

An activity groups devices for one task, e.g. "Shield TV" = TV (IR) + Shield (BLE), "Watch TV" = TV + AV receiver (both IR). Each activity stores:

- a start sequence: power on, select inputs (e.g. TV to HDMI 2), with delays between steps
- an end sequence
- a key map: which device each key and button goes to (D-pad to the Shield, volume to the receiver)
- which device supplies now-playing data, if any

Only one activity runs at a time. "Running" is the remote's own record of what it started; IR and BLE can't tell it whether something else turned the TV off. "All off" sends power-off to every device in the room.

Activities are created and changed in an editor that works on a copy: nothing is saved until **Create** or **Update**, and leaving with changes asks before discarding them.

### Navigation and unsaved changes

- Every way off a page with unsaved changes asks first ("Discard changes to this activity?"): the back arrow, BACK, HOME, the status-bar pill and the tabs. Pages with drafts: the activity and routine editors, Wi-Fi, IR learning.
- The physical BACK and HOME move around the UI wherever they can't mean anything to a device: on editors, settings pages, pickers and the keyboard, and anywhere when nothing is selected and no activity runs. BACK goes back, HOME goes to Activities, and on a question sheet BACK is Cancel. On control pages (the tabs, a device page, an activity page, Now playing) they go to the device as usual.
- While typing, or while a page has unsaved changes, the screen doesn't dim or sleep, for up to 2 minutes after the last touch.
- A disabled Create says why ("Add a device to it first", "Add a step to it first"): an activity needs a device, a routine a step.

### Order

Activities, routines and devices are shown in the order the user sets. Hold a tile or a device: it lifts (accent edge). Drag it out of its own bounds and it trades places with whatever is under the finger, the list scrolling at its top and bottom edges; letting go saves the new order at once. Letting go without leaving it opens its editor instead. All off stays the last activity. Everything that points at a device or an activity by position (activities' devices and roles, routine steps, the selected device, the running activity, the Bluetooth link) follows the move.

### Routines

A routine runs a list of steps with one tap and then is done; unlike an activity it doesn't stay running or take over the keys. They live on the Activities tab behind an **Activities | Routines** switch: tap a tile to run it, hold it to edit (same Create / Update editor as activities).

- Up to 12 routines, 16 steps each. A step is one of:
  - **press a device button**: any function of any device, over its own transport (IR, BLE or HA), pressed 1 to 10 times, 300 ms apart (e.g. volume up × 5);
  - **a Home Assistant action** on an entity, by entity_id: turn on / off / toggle, set brightness, speed, volume, position or temperature, open / close, lock (no unlock from a one-tap routine), activate a scene, run a script, press a button, trigger an automation;
  - **start an activity** (its own start sequence runs; the step ends when it has), or **end the running activity**.
- Each step has a wait after it: 0 to 60 s in 0.5 s steps (none after the last step).
- While one runs, a progress window in the middle of the screen, all text centred, shows the routine, "Step 2 of 4", a progress bar, the current step, a countdown during waits ("Next step in 2.5 s"), what it's waiting for ("Waiting for Home Assistant…", the activity's own progress) and a **Stop** button. The same window shows the end, without changing size: the bar fills, the step line says "Done" and Stop becomes **Close**. It closes by itself 2 s after the last step (4 s if a step couldn't run).
- Radios: Wi-Fi from the start if any step needs Home Assistant (a step waits up to 15 s for HA); Bluetooth to a step's device when it needs it. The remote stays awake until the routine ends.
- A step that can't run (device or activity removed, button missing, HA not set up or not answering, entity gone) is skipped and counted; the routine carries on and ends with "Done, with problems".
- Deleting a device or an activity removes the routine steps that use it.
- When a routine ends (or is stopped), the device or activity that was selected before it (the pill in the status bar) is selected again, even if a step started another activity. Nothing is sent for this: the devices stay as the routine left them; only the keys' target goes back. An activity the routine itself ended (an "End the running activity" step, or starting All off) stays ended.

### Adding a device (on demand only)

- **Bluetooth**: start BLE, advertise as a pairable HID remote (appearance: remote control) for up to 2 minutes, the user picks *Pair accessory* on the TV, the bond is stored, advertising stops.
- **IR, from the library**: brand → model → test-press power → keep. The library is a curated subset of Flipper-IRDB built into the firmware image.
- **IR, learned**: power the receiver, then go key by key: press the old remote's key, the remote captures and decodes it (or keeps the raw timings), confirm by sending it back.
- A device can get its second transport later (e.g. pair the stick first, add the TV's IR codes after).

## 5. Radio policy

| | Wi-Fi | BLE | IR |
|---|---|---|---|
| Home tab showing | on (off 20 s after leaving the tab) | per active target | per active target |
| Any other tab | off (but see open item 1) | on if the active target (selected device, or the running activity's devices) has `ble` | ready if it has `ir` |
| Warm (screen off) | off | stays connected | — |
| Deep sleep | off | off; reconnects on wake | — |

- Changing the active target (another device or activity) shuts the old one's radio down and brings the new one up (~0.2–0.5 s). A device with only `ir` runs no radio at all.
- IR has no standby cost: the RMT channel is set up when a code is sent.
- Wi-Fi and BLE can run together (Home tab with a BLE device selected); ESP-IDF's coexistence shares the radio. Use NimBLE to keep RAM down.
- Setup flows may turn a radio on outside these rules while they run: BLE pairing, IR library download, Wi-Fi setup, firmware update.
- Link state comes from the radio stacks' events (the HAL reports down / connecting / up / failed), never from timers. A link that fails or drops is retried after 2, 5, 10, then every 30 s while it's still wanted; a key for that device tries at once. Bluetooth keys queued for a host that doesn't answer are dropped, never sent to another TV, and a toast says the TV didn't answer.

## 6. Power states

| State | Enters when | Draw (estimate) | Leaves on |
|---|---|---|---|
| Active | any wake, touch or key | ~130–180 mA (backlight ~100 mA of it) | 8 s idle → Dim |
| Dim | 8 s idle | backlight at ~20 % | touch/key → Active; 15 s idle → Warm |
| Warm | screen off | ~2–5 mA (BLE link up, auto light sleep) | touch/key/lift → Active; 2 min → Deep sleep |
| Deep sleep | 2 min warm | ~0.1–0.15 mA | key, touch, lift (ext1, any low) |
| Off | Power off (PWR held 5 s, or Settings > Power off), confirmed | ~0.05–0.08 mA (the LDO's 40 µA is most of it) | PWR held 2 s (ext0, GPIO13); USB shows the charging screen and stays off |

- Idle (Active → Dim) and Sleep (→ screen off) are settings, both counted from the last touch or key. Battery saver overrides them with 5 s and 15 s. Warm → Deep sleep stays at 2 min. On USB, stay warm until unplugged.
- Auto-brightness from the LTR-303ALS (calibrate by eye; the blue window tints it).
- CPU: power management with frequency scaling (80–240 MHz) and auto light sleep while active.
- Before deep sleep: LCD Sleep In, backlight off, FT6236 in monitor mode (never hibernate), MMA8452Q armed for motion (standby if lift doesn't wake it), MAX17048 hibernated, IR receiver off and held, LCD bus pins held. The app passes the wake mask (`hal_deep_sleep`): the keys, touch, lift and USB.
- **Wake-loop guard.** A key that's held down when the remote goes to sleep (under a cushion) is left out of the wake mask, or it would wake it over and over. Three touch or lift wakes in a row that nobody followed up with a touch or key turn that source off until a key wakes the remote. Both are logged.

**Power off.** There is no power switch: the cell feeds the system rail directly and the LDO's enable is tied to it, so Off is the deepest sleep the remote has.
- PWR acts on release: a short press is the normal PWR key. Held 5 s it asks "Power off?" (Cancel / Power off) and the release does nothing. Settings > Power & reset > Power off asks the same.
- Off: stops a routine, forgets the running activity and selected device (nothing is sent), screen, radios and every chip off or in its lowest mode, except the FT6236: monitor mode, never hibernate (its reset is only the power-on RC, so it would stay dead until the battery is disconnected; hardware/README.md), then deep sleep with two wake sources: PWR and USB (CHRG GPIO12 / STDBY GPIO3, RTC pull-ups on; one of them is low whenever USB is in). It goes to sleep only once PWR is let go, since PWR is the wake key. A flag in the RTC block (section 7) marks the wake as "from Off".
- Woken by PWR: the screen stays dark; if PWR is still held 2 s after the wake, the remote boots to the splash with a confirm buzz. Let go sooner and it sleeps again. Touch, lift and the other keys do nothing while off.
- Woken by USB: the charging screen at dim brightness ("Off · hold PWR for 2 s to turn it on"); still off. Unplugged, it sleeps again. A 2 s PWR hold from there turns it on.

Target: about 2 months on a 405085 (~2000 mAh) at 20 short uses a day. The backlight dominates; dim/off timing and brightness are the main levers.

## 7. Wake paths

A wake from deep sleep is a reboot: RAM is gone and the app starts again. What has to survive is in a 1 KB block of RTC memory (`RTC_NOINIT_ATTR`, `app/retained.c`), checked by a magic number (after a power-on it holds garbage), and its device and activity indexes only count if the saved file is still the one they refer to (a hash of it):
- the running activity, the selected device, the last activity, and which devices the remote switched on (and their inputs);
- powered off or just asleep;
- where the screen was: the tab, and the device, activity or Now playing page on it (editors aren't kept);
- the key table: for each key, the code it sends right now;
- the wake-loop guard's counts.

The boot order (`hal_wake_cause` gives the source: key and which one, touch, lift or USB):
- **Key mapped to IR**: `app_early()` sends it from the key table before the display, the file system or the radios are up (target ~30 ms from the press). Still held, it repeats until the release; the app then boots and carries on from that key without sending it again.
- **Key mapped to BLE**: start BLE, directed advertising to the bonded TV, queue the key down (and its up, if it was let go), send on connect (typically 100–500 ms, up to ~2 s).
- **Touch, lift or USB**: the Wake screen over the page that was showing. The touch that woke it isn't passed on (the HAL drops it until the finger lifts).
- **Home tab was showing at sleep**: it comes back with the tab, so Wi-Fi starts too.

The emulator reboots the same way: a new process (or a page reload in the browser) with only what boot.c wrote down, so nothing survives by accident.

**Held keys.** The press starts what the key does and the release ends it: IR repeats at the protocol's own rate (the HAL), Bluetooth sends key down and key up (the TV repeats), and Home Assistant gets volume and D-pad calls again every 250 ms after the first 500 ms.

Wi-Fi fast reconnect: keep the AP's BSSID and channel in RTC memory, static IP (DHCP fallback), target 300–500 ms to an open HA WebSocket.

## 8. Home Assistant (Home tab)

- WebSocket `/api/websocket`, `auth` with a short-lived access token, `call_service` for actions.
- **No long-lived token to type.** The remote signs in the way HA's phone app does and keeps a **refresh token** (NVS, encrypted). On each connect it trades that for a 30-minute access token (`POST /auth/token`, `grant_type=refresh_token`). The token appears in the user's HA profile under Refresh tokens and can be revoked there; Sign out revokes it too.
- **A `client_id` that never changes**, since HA ties the refresh token to it: `https://bleepremote.com/ha/r/<remote ID>/`, with `redirect_uri` `https://bleepremote.com/ha/callback` (same host, so HA accepts it without fetching anything; it checks the scheme and host, not the path). The remote ID is 6 hex digits from the chip's MAC address (`hal_device_id`), shown under Settings > About, so several remotes on one HA, or a remote in each of many homes, each have their own entry in the user's list of refresh tokens and can be revoked one by one. That callback is a static page: it forwards the authorization code to the remote at the LAN address carried in `state` (`http://<remote IP>/ha-callback?code&state`). A new IP from the router later changes nothing. The same static page serves every remote; nothing about a home is stored on bleepremote.com. It's only needed during a phone sign-in (the password sign-in never follows the redirect). For a product: host it somewhere dependable (Cloudflare or GitHub Pages) with access logs off, since the one-time code passes through its URL; and test the https-to-LAN forward on current Android and iOS browsers, as Chrome is tightening access to local networks.
- **Server:** found by mDNS (`_home-assistant._tcp`, name and URL from the TXT record), or typed in. Changing the server signs out.
- **Sign in with a phone** (main way): the remote shows a QR code for a small page it serves on its own IP. The page redirects to the server's `/auth/authorize`; HA's own login page runs on the phone (two-factor and passkeys work), then redirects back to `/ha-callback` on the remote with an authorization code, which the remote exchanges for the refresh token. The remote stays awake while the QR code is up and gives up after 5 minutes.
- **Sign in on the remote** (fallback): username and password on the keyboard, through HA's login-flow API (`/auth/login_flow`), then the two-factor code on the number pad if HA asks for it. The password is sent only to the HA server and never stored.
- `subscribe_entities` for only the entities on the visible page; unsubscribe when the page changes.
- Show the last-known states (cached in flash) at once, with a "connecting" mark until live; queue taps made while connecting.
- Optional: report the remote's battery % to HA.
- Plain HTTP on the LAN (no TLS handshake per wake).

## 9. Bluetooth (Google TV)

- NimBLE, HID over GATT: keyboard report (arrows, Enter) and consumer-control report (AC Home 0x223, AC Back 0x224, volume 0xE9/0xEA, mute 0xE2, play/pause 0xCD, power 0x30). A key is a down report and an empty (up) report; held, the TV repeats.
- Bond with several TVs; connect only to the host of the device the running activity uses, by directed advertising to its address (stored with the device), so only that TV answers.
- While connected and idle, ask for a long connection interval with slave latency.
- To test early on real hardware: the Netflix and YouTube keys (the TV may honour their HID codes only from known remotes), and waking the stick from standby with a BLE key.

## 10. IR

- Send: RMT TX on GPIO45, 38 kHz carrier, 33 % duty. Protocols: NEC/NECext, Samsung32, Sony SIRC (12, 15 and 20 bit), RC5, RC6, Kaseikyo (Panasonic), raw. While a key is held: NEC-style repeat codes every ~108 ms, Sony and RC5/RC6 the whole frame (RC5/RC6 keep the toggle bit, which flips on the next press); Sony always at least 3 frames.
- Learn: GPIO1 high, wait 100 ms, RMT RX on GPIO42 (active low, already demodulated), IR LEDs off; decode to a known protocol or keep raw. GPIO1 low and no pull-up on GPIO42 afterwards. The carrier can't be measured; learned codes are sent at 38 kHz.
- Library: curated Flipper-IRDB subset in the firmware image.

## 11. Setup, settings, updates

- First boot: Wi-Fi setup on the device (Settings > Wi-Fi: Scan, then Connect), then Home Assistant sign-in (Settings > Home Assistant).
- Config (settings, devices, activities, routines and their order) is JSON in LittleFS, `/config.json` (`app/config.c`):
  - written 2 s after the last change, and at once before deep sleep, power off and a firmware restart; to `/config.tmp` first, then renamed over, so a reset mid-write keeps the old file;
  - versioned (`"version": 1`); functions, kinds, icons, step kinds and actions are stored by name, not by number, so a later firmware still reads it. A missing field keeps its default; unknown fields, functions and step kinds are skipped; values are clamped; references to devices or activities that aren't there are dropped;
  - **backwards compatible, always**: every newer firmware must load the setup saved by any older one, with nothing lost (the owner's requirement). Keys and names are only ever added, never renamed, removed or reused; new fields have defaults; a change of meaning bumps the version with an upgrade step. Each released version has a frozen fixture (`sim/tests/fixtures/config-vN.json`) and a scenario that must keep loading it. The rules are spelled out at the top of `app/config.h`;
  - the Wi-Fi password is not in it: it goes to NVS (encrypted), like the Home Assistant refresh token; written only when it changes. NVS encryption uses the HMAC scheme (`CONFIG_NVS_SEC_KEY_PROTECT_USING_HMAC`): its key is derived from an HMAC key in an eFuse block, generated and burned on the first boot and unreadable by software, so no flash encryption is needed;
  - first boot (or a factory reset): the factory defaults are saved straight away;
  - not saved, by design: the running activity, the selected device and the last activity (RTC memory: they survive deep sleep, not a reset or power off), and screen state (the Home tab's room, the Activities/Routines switch).
- On-device editing where the design has it, plus a **setup site on bleepremote.com over USB**. The ESP32-S3's USB port is Serial/JTAG only (it can't be a network adapter or a drive), so the page talks to the remote with WebSerial (Chrome, Edge): read and write the setup's JSON, back it up and restore it, import Flipper `.ir` files, and flash firmware (esp-web-tools).
- Firmware updates over Wi-Fi from bleepremote.com (Settings > Software update, `app/update.c`):
  - Check: `GET https://bleepremote.com/fw/stable.json` → `{"version", "url", "size", "sha256", "notes"}`, over HTTPS with the ESP-IDF certificate bundle. A manual check turns Wi-Fi on for itself (a setup flow, section 5). The optional daily check runs only while Wi-Fi is already on, and never turns it on.
  - Install: only while on USB; unplugging stops it. `esp_https_ota` streams the image into the idle OTA slot, checks the SHA-256 and the image signature (`CONFIG_SECURE_SIGNED_APPS_NO_SECURE_BOOT` with the RSA scheme: on the ESP32-S3 that's RSA-3072, the Secure Boot v2 format; no eFuses burned for it; the key is kept off the website), then sets it as the boot slot and restarts. A stopped or failed download leaves the running slot untouched.
  - Rollback: `CONFIG_BOOTLOADER_APP_ROLLBACK_ENABLE`. A new image boots "pending verify" and marks itself valid once `app_init()` has finished (`hal_fw_boot_ok()`); if it crashes or resets before that, the bootloader goes back to the previous slot.
  - Hosting: static files on the domain (the manifest plus `bleep-<version>.bin`), e.g. GitHub Pages or Cloudflare Pages. Release = build, sign, upload the .bin, then update the manifest last.
  - USB-serial flashing (`idf.py flash` over the USB-Serial/JTAG port) always works too, so a bad release can't brick the remote.
- Settings, in groups under the battery card:
  - **Remote**: *Display & haptics* (brightness, theme, layout, haptics strength) and *Power & sleep* (idle and sleep timeouts, wake on pick-up, battery saver), each a page of its own;
  - **Connections**: Wi-Fi, Home Assistant;
  - **System**: Software update, About;
  - **Power & reset**: Power off, and Reset to factory settings (asks first, in amber: signs out of Home Assistant, which revokes the refresh token if HA is reachable, erases the config file, the secrets' NVS and the Bluetooth bonds, saves the defaults and restarts as a new remote).
- Layout (Display & haptics): activities and routines, and devices, each as a **grid** of tiles (two columns) or a **list** of full-width rows. Defaults: activities and routines as a grid, devices as a list. Both layouts work the same: tap, hold to edit, hold and drag to move.

## 12. Stack

- ESP-IDF 5.x, C.
- LVGL 9 on `esp_lcd` i80 (8-bit, ILI9488, 320 × 480, RGB565). Two partial draw buffers in internal DMA RAM.
- NimBLE for BLE HID, ESP-IDF Wi-Fi + `esp_websocket_client`, RMT for IR.
- Sensors: the fuel gauge and the light sensor are read once a second, never from a hot path; USB is two GPIOs, polled every tick.
- PSRAM (2 MB, quad): the model (~30 KB, `HAL_PSRAM` = `EXT_RAM_BSS_ATTR`, needs `CONFIG_SPIRAM_ALLOW_BSS_SEG_EXTERNAL_MEMORY`), the setup's JSON (up to 256 KB) and its cJSON tree (`hal_big_alloc`), and caches. Internal RAM is for Wi-Fi, NimBLE and LVGL's draw buffers.
- Flash (8 MB): two OTA app slots + LittleFS. Partition table:

  | Name | Type | Size |
  |---|---|---|
  | nvs | data/nvs | 24 KB |
  | otadata | data/ota | 8 KB |
  | phy_init | data/phy | 4 KB |
  | ota_0 | app | 3 MB |
  | ota_1 | app | 3 MB |
  | storage | data/littlefs | ~1.9 MB (the rest) |

  The image (LVGL, fonts, NimBLE, Wi-Fi, IR library) is expected at 1.5 to 2 MB, so 3 MB slots leave room to grow.

## 13. Build order

1. **Base**: display, touch, keys, haptics, light sensor, fuel gauge; power states and sleep/wake, with current measured in each state.
2. **Device manager**: device storage, selection, radio policy, key routing, the Devices tab, tested with a dummy transport.
3. **Wi-Fi + Home Assistant**: setup, fast reconnect, the Home tab.
4. **Google TV over BLE**: HID, pairing, reconnect on wake.
5. **IR**: send, learn, library.

## 14. Open

Decisions needed (the design and the radio rules disagree):

1. **Wi-Fi-only devices in activities.** Sonos, Kodi and Apple TV are normally controlled through HA, so those activities need Wi-Fi outside the Home tab. Proposal: a device can have an `ha` transport, and Wi-Fi is on while the running activity uses one.
2. **Now playing for Google TV.** BLE HID only sends keys; title, artwork and progress (Now playing, the Wake resume card, the lock-screen mini card) can only come from HA's media_player, which means Wi-Fi. Options: show transport controls without metadata for BLE devices, or let an activity name an HA media_player as its now-playing source (Wi-Fi on while the screen is on).
3. **Clock.** The lock screen shows the time. With no 32 kHz crystal, the RTC runs on the internal RC oscillator and drifts in deep sleep (possibly minutes a day; measure on the board). It needs an SNTP sync from time to time, which means a short Wi-Fi connection outside the Home tab, or hiding the clock when the last sync is too old.
4. **Lock / ambient screen.** If it stays lit while idle, it costs ~100 mA. Proposal: it is the Dim state (low backlight for a few seconds, then off), and it stays on only while on USB.
5. **Volume overlay level.** IR and BLE give no volume feedback, so the "32" level can only be shown for HA media players. For IR/BLE volume, show +/− feedback without a number.
6. **Battery saver** (low-battery sheet): define it. Proposal: lower brightness cap, shorter timeouts, lift-to-wake off.
7. ~~**HA token entry.**~~ Decided: no token entry. Sign in with a phone (QR code) or on the remote with username and password, keeping a refresh token (section 8).

Other open items:

- Netflix/YouTube keys and wake-from-standby over BLE: test on the real stick.
- Exact IR library subset (which brands).

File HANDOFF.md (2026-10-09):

# Handoff: Bleep (esp-remote), state on 2026-10-09 (flat back done)

This file carries the working state to another PC. Claude's memory and the chat history stay on the old PC (see "Moving to another PC" at the end), so start the new session by asking Claude to read this file.

## Where things stand

- **Main board: LOCKED and in production.** Bleep v1 was ordered from JLCPCB on 2026-10-08: 5 boards, 0.8 mm, green mask, HASL, Economic assembly of 2. Never edit or regenerate anything in `hardware/mainboard/`. Its files are read-only, `./build.sh pcb` refuses, and `python hardware/layout.py` stops with "PCB LOCKED" if a shell change would move a value in `mainboard/pcb_lock.json`. Only the shell (enclosure) and the firmware may change.
- **JLCPCB polarity question (2026-10-09), answered.** JLCPCB asked us to confirm the SMD polarities in their 2D picture, where U6 (the IR receiver) is marked "Corrected Part". Every pin-1 and polarity mark matched the board file: D1/D2 lens to the top edge, cathode on the right; D3 cathode on the left; Q1–Q3; U2–U8; J1 pin 1 at the left end; J3. A reply saying to proceed was drafted for the user to send. D3's anode route runs under the diode body, where their picture hides it. DRC is 0 unconnected.
- **Shell: flat back, 4 mm cell (2026-10-09).**
  - The shell is still 60.7 × 182.2 × 12.95 mm.
  - Screws (2026-10-09, the user's request): the board screws straight onto the four key-area posts with 4 × M2×4 from its underside (nylon, because a VBAT track passes under the head at H1), and the back plate takes only the 2 bottom M2×8 screws plus its top snap fingers. The plate lost the four key-area standoffs and holes.
  - The back plate is now flat: the support platform and its pockets are gone. The 4.5 mm between the plate and the board is open. The board rests on rails along its side edges (under the screen only, from the top end; no ledge along the top edge, so the cell gets that length), a standoff round each of the plate's 2 bottom screws, and a 3 mm pillar under each key switch (PWR has none: it sits over the ESP32 module).
  - Cells up to 4.0 × 50.8 × 86.1 mm fit under the screen. `BATT = (50, 85, 4.0)` in `hardware/layout.py` (a 405085, the user's pick); four corner guides on the plate locate the cell, so set `BATT` to the cell actually bought and rebuild.
  - Windows (2026-10-09): two separate prints in translucent PETG (the user picked Creality CR-PETG Translucent Blue), fitted by hand with glue: `stl/ir_window.stl`, a flanged plug pushed into the IR slot from inside, and `stl/sensor_window.stl`, the pill with pegs through its holes, the light sensor's running on as a light pipe to 0.5 mm above it. 0.1 mm clearance per side.
  - Battery leads are soldered straight to the BAT+/BAT− pads; there's no connector. The motor sticks to the board's underside.
  - STLs are in `hardware/enclosure/stl/`. Fit checks pass; the interference check has zero volume (surfaces touch only).
  - 3D viewer: https://claude.ai/artifact/5qHsgfE1eNkeLNL5kHZQUn (version 15, source in `hardware/viewer/`).
  - `docs/back-plate.png` and `docs/enclosure-assembly.png` still show the old platform: they need a machine with a display to re-render.
- **Display and battery: ordered (2026-10-09), waiting for delivery.** If the cell that arrives isn't a 405085, set `BATT` in `hardware/layout.py` to its size and rebuild the back plate. Background on the cell: look for a flat Li-Po up to 4.0 mm thick and 50.8 × 86.1 mm: the user wants a 405085 (4.0 × 50 × 85 mm). Shipping constraints:
  - Li-Po won't ship to Cyprus: Kaufland and Amazon/Akyga refuse.
  - The user has a German forwarding service, prefers Amazon, and wants the cheapest option.
  - Eremit ships within Germany and allows forwarders.

## Tried and rejected (don't propose again unprompted)

- **Eremit 654060 cell** (6.4 × 40 × 60 mm, 2000 mAh, €6.89). It made the shell 15.35 mm thick: "too thick".
- **Tapered key end** (back sloping from 15.35 to 10.15 mm, two-part back plate): "undo the slanted profile".

## Done: flat back (2026-10-09)

The user asked for a flat back panel to free room under the board and fit a larger battery, and chose both: open up the underside and enlarge the cell area. Done as described above. The board didn't change, and neither did the shell's thickness.

Not done, offered only: below the module, between the motor and the right-hand screws, there's open room of about 38 × 48 mm. It could take a second, smaller cell wired in parallel, but that isn't recommended.

## Next

Firmware: ESP-IDF or Arduino + LVGL. Hardware facts the firmware needs are in `hardware/README.md`: pin map, IR receiver power on GPIO1, standby budget, fuel gauge.

## Build tools

- Python 3, no extra packages (the viewer build no longer uses `trimesh`)
- OpenSCAD 2021.01+: `build.sh` uses `openscad` from the PATH, else `/c/Program Files/OpenSCAD/openscad.com`, or set `OPENSCAD`. On the Linux PC (no sudo) it's the extracted AppImage plus locally unpacked libraries in `~/.local/share/bleep/`, run through the wrapper `~/.local/bin/openscad`. With no display, the PNG renders are skipped.
- KiCad 10: only needed to read the locked board
- Freerouting 2.5 + Java 25: not needed any more, because the board is locked

Commands:

- `cd hardware && ./build.sh enclosure` builds the STLs, renders and fit checks.
- `./build.sh viewer` builds the meshes for the 3D viewer.

## Moving to another PC

Clone the repo. A copy of Claude's memory for this project is in `.claude/memory/`, taken on 2026-10-09. On the new PC, copy those files into Claude's memory folder for the project: `%USERPROFILE%\.claude\projects\<project path with \ : and spaces as ->\memory\`. For example, the folder is `C--Users-ioann-projects-esp-remote` if the project sits at `C:\Users\ioann\projects\esp-remote`. Or ask Claude to restore them. The copy in the repo doesn't update itself; re-copy it after memory changes.

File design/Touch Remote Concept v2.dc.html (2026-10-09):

DIY TOUCH REMOTE · CONCEPT PACK v2 · MODULE BUILD

# Touchscreen universal remote

Slim bar with a 3.5″ touch screen on top and 14 hardware keys below. Built from an off-the-shelf ESP32-S3 3.5″ display board, a few breakout modules and one through-hole key PCB, with a 2000 mAh Li-Po and USB-C charging, in a 3D-printed FDM enclosure. Controls IR devices directly and everything else through Home Assistant over Wi-Fi.

01

## Industrial design, three directions

Drawn at 3 px per mm at the original custom-PCB size. The module build in section 04 needs a larger shell, about 66 × 196 × 20 mm.

1a

Monolith

58 × 178 × 16 mm

Flat slab with an even thickness. The battery sits behind the key area. Two flat shells, so the visible faces print without supports.

21:4082%

Living room

Activities

Watch TV

Shield TV

Apple TV

Kodi

Sonos

All off

PWR

HOME

BACK

OK

YOUTUBE

NETFLIX

PLEX

−VOL+

MUTE

Front

58 × 178 mm

Side

16 mm

Top · IR window

Bottom · USB-C

+Simplest print and assembly; sits flat on a table.

+Most internal volume for a bigger battery later.

−Plainest in the hand; weight is spread evenly.

1b

Pebble

SELECTED

56 × 184 × 16 mm

Even 16 mm thickness with a flat back. The wide radius at the bottom end rests in the palm, and the D-pad sits directly under the screen, in reach of the thumb.

21:4082%

Living room

Activities

Watch TV

Shield TV

Apple TV

Kodi

Sonos

All off

OK

BACK

HOME

MUTE

YOUTUBE

NETFLIX

PLEX

−VOL+

Front

56 × 184 mm

Side

16 mm

Top · IR window

Bottom · USB-C

+D-pad and app keys in thumb reach without shifting grip.

+Flat back prints without supports and sits flat on a table.

−Large bottom radius leaves a little less room beside the battery.

1c

Deck

60 × 176 × 17 mm

Chamfered edges, a recessed screen, and the keys on a separate inset plate. The plate can be printed in a contrasting colour or texture.

21:4082%

Living room

Activities

Watch TV

Shield TV

Apple TV

Kodi

Sonos

All off

PWR

HOME

BACK

MUTE

OK

−VOL+

YOUTUBE

NETFLIX

PLEX

Front

60 × 176 mm

Side

17 mm

Top · IR window

Bottom · USB-C

+Key plate is a separate part: swap colour or material freely.

+Chamfers hide FDM layer lines at the edges.

−Widest and thickest of the three.

02

## Touchscreen UI

Shown at 1:1 for the 320 × 480 panel. Built with LVGL on the ESP32-S3. The hardware keys handle navigation and volume, so the screen is for choosing activities, showing state, and extra functions.

21:40

82%

Living room

Activities

Watch TV

TV + AV receiver

Shield TV

Running

Apple TV

TV + Apple TV

Kodi

TV + Kodi box

Sonos

Music, TV off

All off

Every device in room

Activities

Devices

Home

Settings

Activities

Home screen after pick-up. One tap powers on and switches inputs on every device in the activity.

21:40

82%

Shield TV · Plex

End ×

artwork

Film title

2021 · 2 h 08 m

1:12:402:08:15

−10

+30

Subtitles

Audio

Info

Now playing

Shown while an activity runs. Metadata comes from Home Assistant's media player; D-pad and volume keys stay on the hardware.

21:40

82%

Home Assistant

Living room

Living room

Kitchen

Bedroom

Ceiling light

70%

Floor lamp

Off

Thermostat

Now 21.5°

−

21°

+

Movie

Bright

Off

Activities

Devices

Home

Settings

Home

Lights, climate and scenes through Home Assistant over Wi-Fi. Zigbee and Thread devices appear here via HA.

21:40

82%

Devices · IR

Living room TV

INPUT

HDMI 1

HDMI 2

HDMI 3

HDMI 4

KEYPAD

1

2

3

4

5

6

7

8

9

Guide

0

Menu

Activities

Devices

Home

Settings

Device page

Extra IR functions per device. Codes come from a database or are entered per device; the hardware keys send the matching codes.

21:40

82%

Remote

Settings

82%

about 8 days left

USB-C · not charging

BrightnessAuto

Wake on pick-up

HapticsMedium

Sleep after30 s

Home AssistantConnected

Activities

Devices

Home

Settings

Settings

Battery from the fuel gauge, auto-brightness from the light sensor, and wake behaviour.

03

## Off-the-shelf architecture

One ESP32-S3 display board does most of the work. Three small modules and one through-hole key PCB cover the rest.

USB-C extension

Short panel-mount lead to the bottom end

Li-Po 2000 mAh

704060 · MX1.25 2-pin

PWR key

One tact switch, wired to MCP23017

USB-C

MX1.25

→ MCP23017

MAIN BOARD · OFF THE SHELF

Waveshare ESP32-S3-Touch-LCD-3.5

ESP32-S3R8 · 16 MB flash · 8 MB PSRAM3.5″ IPS 320 × 480 · ST7796 + FT6336 touchAXP2101: charging, battery level, power keyQMI8658 IMU: wake on pick-upPCF85063 RTC · USB-C · BOOT / PWR buttons

Unused on board: camera, audio codec, mic, TF slot

I²C + INT

MCP23017 module

Scans the key PCB · INT wakes the MCU

I²C

DRV2605L module

Drives an LRA coin motor

I²C

BH1750 module (optional)

Auto-brightness · needs a bezel window

GPIO · RMT

IR transmitter module

940 nm, transistor-driven

2.4 GHz

Wi-Fi · BLE

Home Assistant API · BLE HID

I²C addresses: MCP23017 0x20, BH1750 0x23, DRV2605L 0x5A. None of these clash with the board's onboard devices (touch 0x38, AXP2101 0x34, IMU 0x6B, RTC 0x51, codec 0x18).

RECOMMENDED

≈ $26–39

Waveshare ESP32-S3-Touch-LCD-3.5

Listing ↗ (https://www.aliexpress.us/item/3256808870605293.html)

+Charger, battery gauge, IMU and power key already on board, so 3 fewer modules

+ST7796 / FT6336 are widely supported in LVGL and ESPHome

+Documented pinout, schematic and dimension drawing

−About $10 more than the Guition board

−Carries parts you won't use (camera, audio)

BUDGET

≈ $17–30

Guition JC3248W535 ("better CYD")

Listing ↗ (https://www.aliexpress.us/item/3256808306886024.html)Alt listing ↗ (https://aliexpress.com/item/1005008275169229.html)

+Cheapest 3.5″ capacitive ESP32-S3 board, 16 MB / 8 MB

+LiPo charging on board, ~12 free GPIO

+94.5 × 62 mm outline is published

−No IMU: add an accelerometer module (LIS3DH / MPU-6050)

−No fuel gauge; battery level is less accurate

−AXS15231B QSPI driver has less library support

04

## Internal layout

Placement inside the 1b shape at 3 px per mm. Both views are seen from the front.

Fit check against 1b

Off-the-shelf boards don't fit the 56 × 184 × 16 mm shell. This layout needs about 66 × 196 × 20 mm. Width comes from the main board and thickness from its back-side parts, so measure the board before modelling the shell.

1

2

5

3

active area 49 × 73

UP

LEFT

OK

RIGHT

DOWN

BACK

HOME

MUTE

YT

NFLX

PLEX

VOL−

VOL+

4

Front (behind the shell)

6

7

8

9

10

11

Back (x-ray from front)

1IR transmitter module at the top end, behind the IR window

2PWR key: one tact switch on a scrap of perfboard, wired to the MCP23017

3Main board, ≈ 62 × 95 mm. Confirm with the Waveshare dimension drawing

4Key PCB, 62 × 70 mm, the only custom board: 13× 6 × 6 mm through-hole switches

5Optional BH1750 module behind a small bezel window

6Li-Po 704060 (7 × 40 × 60 mm) on the back of the main board, foam pad + swell gap

7MCP23017 module, soldered flat to the back of the key PCB on a pin header

8DRV2605L module (≈ 16 × 18 mm)

9LRA coin motor, glued to the shell in the grip area

10USB-C extension from the board port to a panel-mount socket at the bottom

11Harness from the board header: 3V3, GND, SDA, SCL, INT, IR

Key PCB

2-layer, through-hole only, no SMD parts. 13 switches, a 6-pin header for the harness, a footprint to solder the MCP23017 module flat on the back, 2 pads for the PWR switch wires and 3 M2 mounting holes. Rows and columns go straight to the MCP23017 pins, so there's no diode matrix.

Stack-up through the screen area (estimate)

Front bezel lip

1.0

Main board (glass to back parts)

9.0

Foam

0.5

Li-Po battery

7.0

Swell gap

0.7

Back shell

1.8

Total20.0

05

## Parts list and spec sheet

ROLE | SEARCH FOR | QTY | PRICE | NOTES | LINK
Main board | Waveshare ESP32-S3-Touch-LCD-3.5 (no camera, no case) | 1 | ≈ $26–39 | Listing seen at $28.22 | Listing ↗ (https://www.aliexpress.us/item/3256808870605293.html)
Battery | 3.7 V 2000 mAh Li-Po 704060, MX1.25 2-pin | 1 | ≈ $3.70 | Check plug polarity against the board before connecting | Listing ↗ (https://www.aliexpress.us/item/3256809668623187.html)
Key scanner | MCP23017 I/O expander module | 1 | ≈ $1–3 | | Search ↗ (https://www.aliexpress.com/w/wholesale-mcp23017-expander.html)
Haptic driver | DRV2605L module | 1 | ≈ $1–5 | | Listing ↗ (https://www.aliexpress.us/item/3256812018709953.html) · Alt ↗ (https://www.aliexpress.us/item/2255801071277560.html)
Haptic motor | LRA coin motor, 0832 or 1027 | 1 | ≈ $1–2 | | Search ↗ (https://www.aliexpress.com/w/wholesale-lra-linear-vibration-motor.html)
IR | IR transmitter module, 940 nm, with transistor driver | 1 | ≈ $1–2 | Two or more LEDs for better range | Search ↗ (https://www.aliexpress.com/w/wholesale-ir-transmitter-module.html)
USB-C | USB-C extension, short, panel-mount | 1 | ≈ $2–4 | Low-profile right-angle plug | Search ↗ (https://www.aliexpress.com/w/wholesale-usb-c-panel-mount-extension.html)
Switches | 6 × 6 × 5 mm through-hole tact switch | 14 | ≈ $1 / 100 | | Search ↗ (https://www.aliexpress.com/w/wholesale-6x6x5-tactile-switch.html)
Key PCB | Custom 2-layer, through-hole only | 1 | ≈ $2–5 | 5-piece minimum at most fabs, plus shipping
Light sensor | BH1750 (GY-302) module | 0–1 | ≈ $1–2 | Optional | Search ↗ (https://www.aliexpress.com/w/wholesale-bh1750.html)
Hardware | Wire, M2 heat-set inserts + screws, PETG filament, translucent blue PETG for the IR and sensor windows | 1 set | ≈ $3–5 | | Search ↗ (https://www.aliexpress.com/w/wholesale-m2-heat-set-insert.html)
Total | | | ≈ $42–70 | Budget board saves about $8–10

Prices for the main boards, battery, MCP23017 and DRV2605L come from AliExpress listings in October 2026. Many low prices are first-order deals, so the ranges show the regular price too. Other prices are typical ranges; check them before ordering. "Listing" links go to a specific product seen during research; "Search" links open an AliExpress search, so pick a seller with good ratings and recent sales.

Your shortlist

Links you found. Not yet matched to the parts above.

01item/1005013004590116 ↗ (https://www.aliexpress.com/item/1005013004590116.html)02item/1005013161919671 ↗ (https://www.aliexpress.com/item/1005013161919671.html)03item/1005008919492354 ↗ (https://www.aliexpress.com/item/1005008919492354.html)04item/1005012356004640 ↗ (https://www.aliexpress.com/item/1005012356004640.html)05item/32714713175 ↗ (https://www.aliexpress.com/item/32714713175.html)06item/1005012205024705 ↗ (https://www.aliexpress.com/item/1005012205024705.html)07item/1005010291152522 ↗ (https://www.aliexpress.com/item/1005010291152522.html)08item/1005013205727318 ↗ (https://www.aliexpress.com/item/1005013205727318.html)

Spec sheet

Dimensions (est.)≈ 66 × 196 × 20 mm, set by the main board

Display3.5″ IPS, 320 × 480, capacitive touch

ProcessorESP32-S3R8, 16 MB flash, 8 MB PSRAM

WirelessWi-Fi 4 (2.4 GHz), Bluetooth LE 5

Thread / ZigbeeNot on device; handled by Home Assistant

IRTransmitter module, 940 nm

Keys14: Power, Home, Back, Mute, D-pad + OK, Vol ±, YouTube, Netflix, Plex

SensorsQMI8658 IMU (on board), LRA haptics, optional BH1750

Battery2000 mAh Li-Po 704060, MX1.25

ChargingUSB-C through the board's AXP2101, extended to the bottom end

Battery lifeMeasure on your build. Dev boards draw more in sleep than a custom PCB; removing the board's power LED helps.

Custom PCBOne key PCB, through-hole only

FirmwareESPHome with LVGL, or Arduino / ESP-IDF + LVGL. HA native API; BLE HID for Shield / Fire TV.

EnclosureFDM PETG, two shells, M2 inserts; IR and sensor windows in translucent blue PETG

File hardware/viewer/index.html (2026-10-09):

CONCEPT 1b · v1 SLIM · OWN MAIN BOARD

# Bleep

60.7 × 182.2 × 13.0 mm · 14 keys · 3.5″ 320×480

Turntable X-ray + labels Explode

3/4 Front Back Side IR end USB-C end Low angle

Loading model…

## Colorways

## Parts

## PETG colors

Custom Apply to all keys

## Finish

Matte Satin Gloss

## Screen

Off Activities Playing Home

## Filament list

Copy color list

The geometry is the real print files from hardware/enclosure. Labels and icons are flush two-color inlays: print caps.stl with caps_labels.stl added as a second part on a multi-material printer. The IR and sensor windows are small separate prints in translucent blue PETG (ir_window.stl, sensor_window.stl).

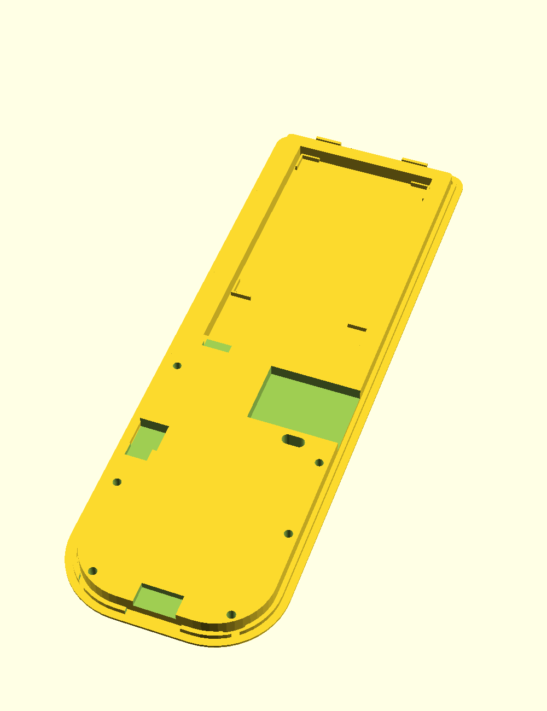
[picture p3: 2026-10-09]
hardware/docs/back-plate.png

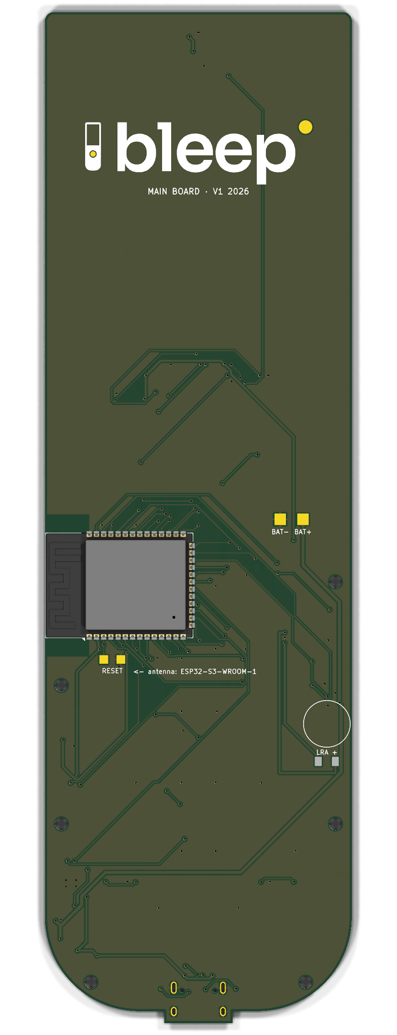
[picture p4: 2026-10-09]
hardware/docs/mainboard-bottom.png

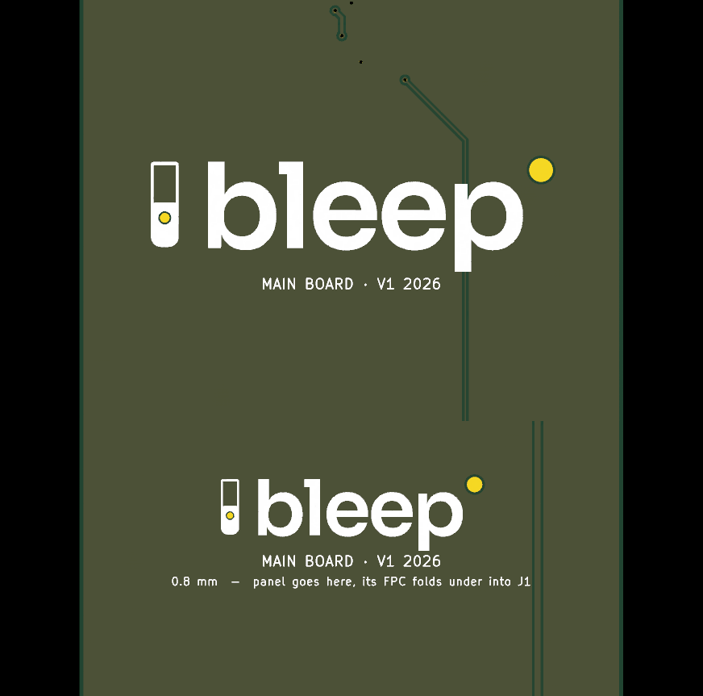
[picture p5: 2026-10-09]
hardware/docs/mainboard-branding.png

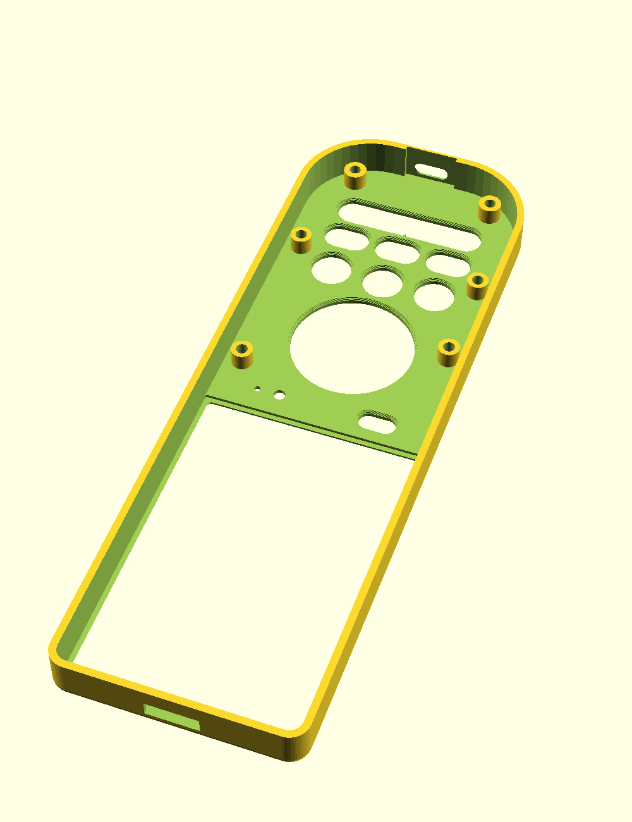
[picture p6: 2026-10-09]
hardware/docs/front-shell-inside.png

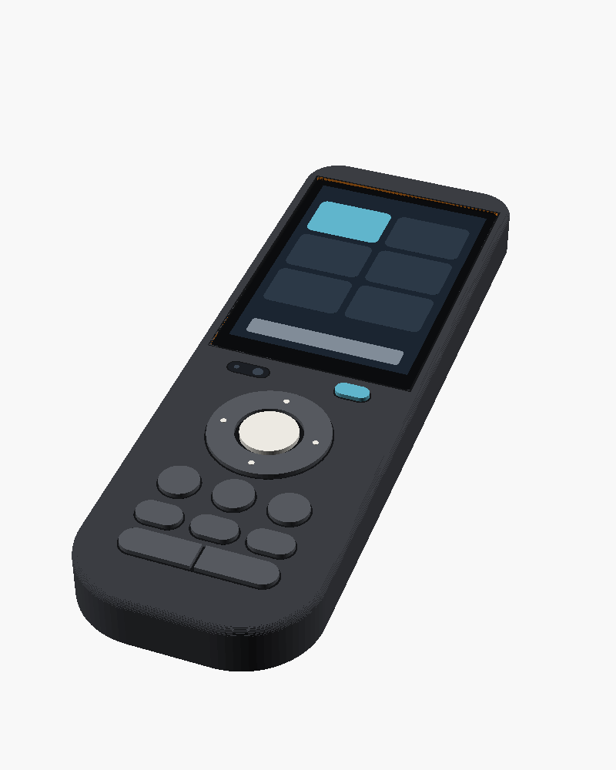
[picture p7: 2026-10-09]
hardware/concepts/slim_3d4.png

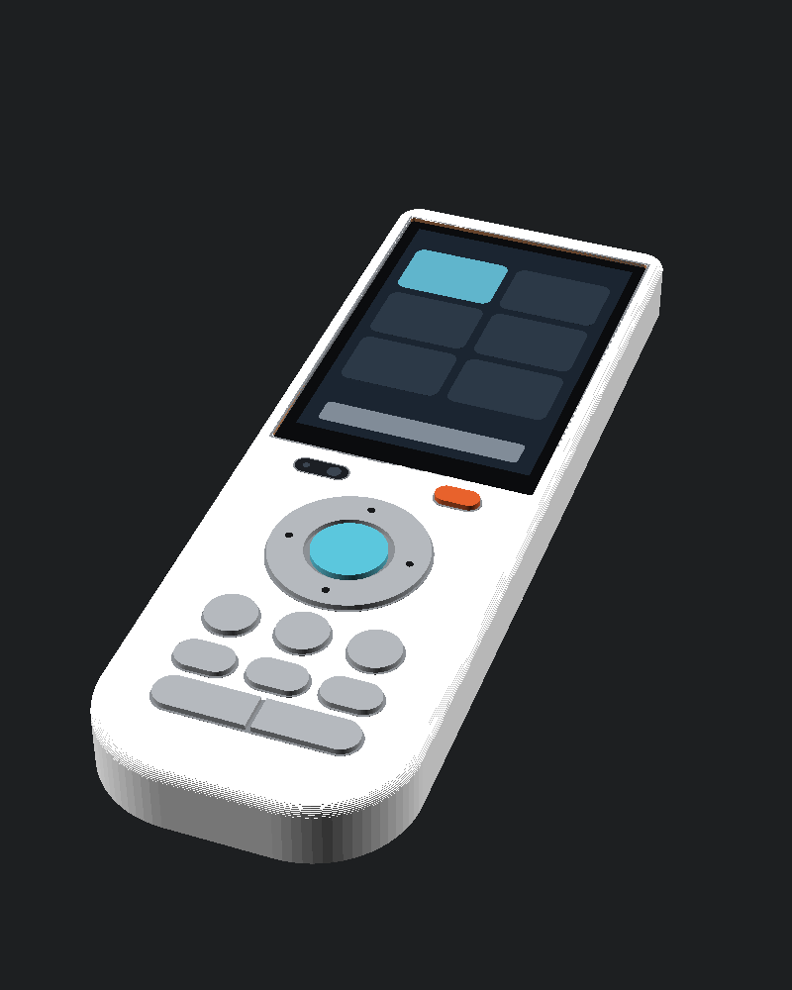
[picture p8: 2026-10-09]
hardware/concepts/arc_3d5.png

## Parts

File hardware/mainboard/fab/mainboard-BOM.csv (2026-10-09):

Comment | Designator | Footprint | LCSC Part #
100R | R4,R8 | R_0603_1608Metric | C22775
100k | R5,R9,R11,R19 | R_0603_1608Metric | C25803
100nF | C2,C9,C13 | C_0603_1608Metric | C14663
10k | R1,R10 | R_0603_1608Metric | C25804
10uF | C6 | C_0603_1608Metric | C19702
10uF | C5,C11,C12,C14,C16 | C_0805_2012Metric | C15850
1uF | C3,C4,C7,C8,C15,C17,C18 | C_0603_1608Metric | C15849
220R | R20 | R_0603_1608Metric | C22962
22R | R2,R3 | R_0603_1608Metric | C23345
22R | R6,R7 | R_1206_3216Metric | C17958
22uF | C1 | C_0805_2012Metric | C45783
3.3k | R16 | R_0603_1608Metric | C22978
4.7k | R12,R13 | R_0603_1608Metric | C23162
5.1k | R17,R18 | R_0603_1608Metric | C23186
AO3400A | Q1,Q2 | SOT-23 | C20917
AO3401A | Q3 | SOT-23 | C15127
B5819W | D3 | D_SOD-123 | C8598
DRV2605LDGST | U3 | MSOP-10_3x3mm_P0.5mm | C425927
FPC-05F-50PH15 | J1 | FPC-05F-50PH15 | C2856826
IRM-H638T/TR2 | U6 | IRM-H638T | C91447
LTR-303ALS-01 | U7 | LTR-303ALS-01 | C364577
MAX17048G+T10 | U8 | MAX17048_TDFN-8_2x2mm | C2682616
ME6211C33M5G-N | U2 | SOT-23-5 | C82942
MMA8452QR1 | U4 | MMA8452Q_QFN-16_3x3mm_P0.5mm | C11360
TP4056 | U5 | SOIC-8-1EP_3.9x4.9mm_P1.27mm_EP2.41x3.3mm | C16581
TS-1187A-B-A-B | SW1,SW2,SW3,SW4,SW5,SW6,SW7,SW8,SW9,SW10,SW11,SW12,SW13,SW14 | SW_Push_1P1T_XKB_TS-1187A | C318884
TYPE-C 16PIN 2MD(073) | J3 | USB_C_Receptacle_HRO_TYPE-C-31-M-12 | C2765186
VSMB2948SL | D1,D2 | VSMB2948SL_SideView | C6604342

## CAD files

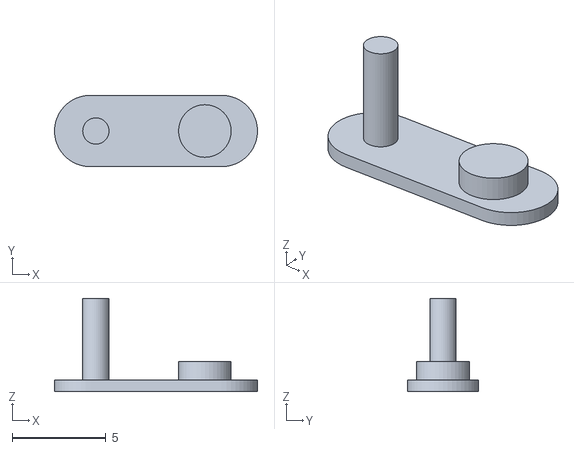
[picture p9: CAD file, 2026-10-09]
hardware/enclosure/stl/sensor_window.stl
10.8 x 3.80 x 4.95

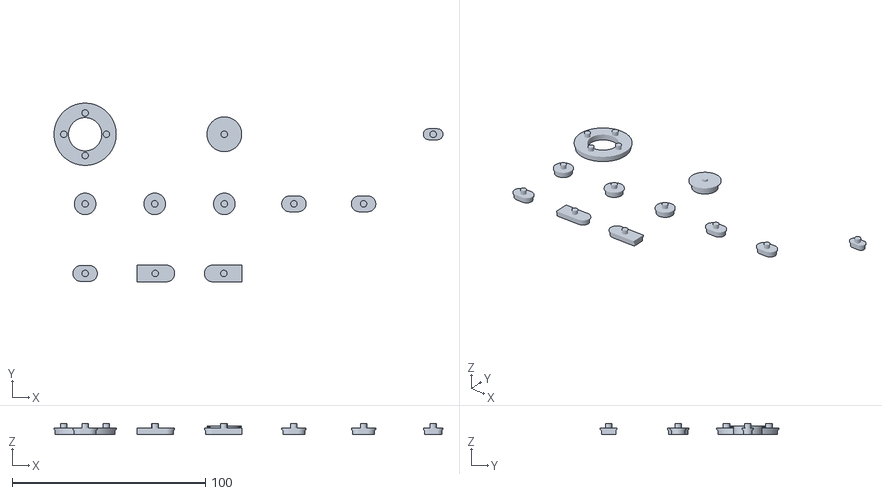
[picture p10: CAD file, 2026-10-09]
hardware/enclosure/stl/caps.stl
201.2 x 92.4 x 5.86

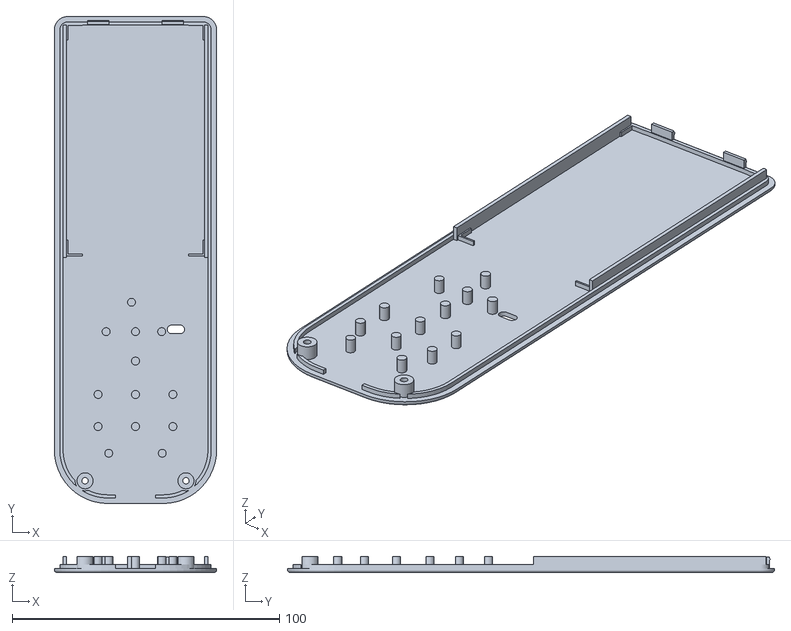
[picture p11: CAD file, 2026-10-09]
hardware/enclosure/stl/back_plate.stl
60.7 x 182.2 x 6.00

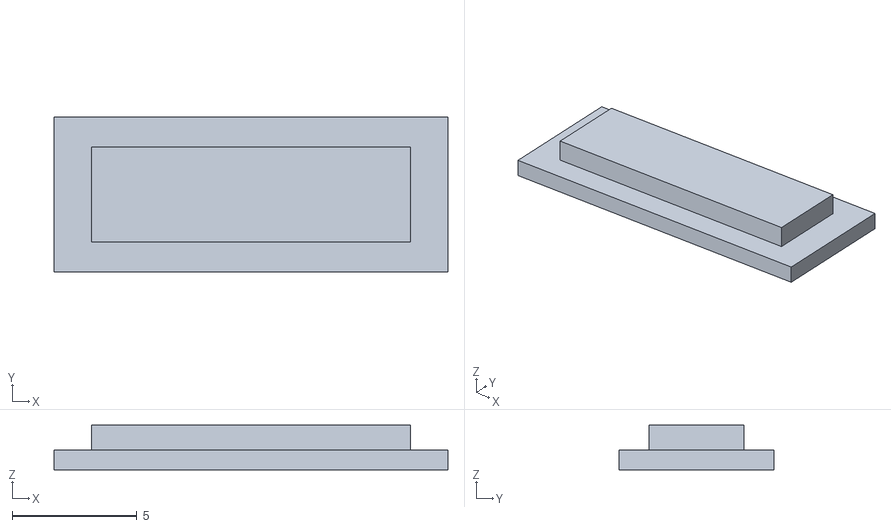
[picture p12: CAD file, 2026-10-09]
hardware/enclosure/stl/ir_window.stl
15.8 x 6.20 x 1.80

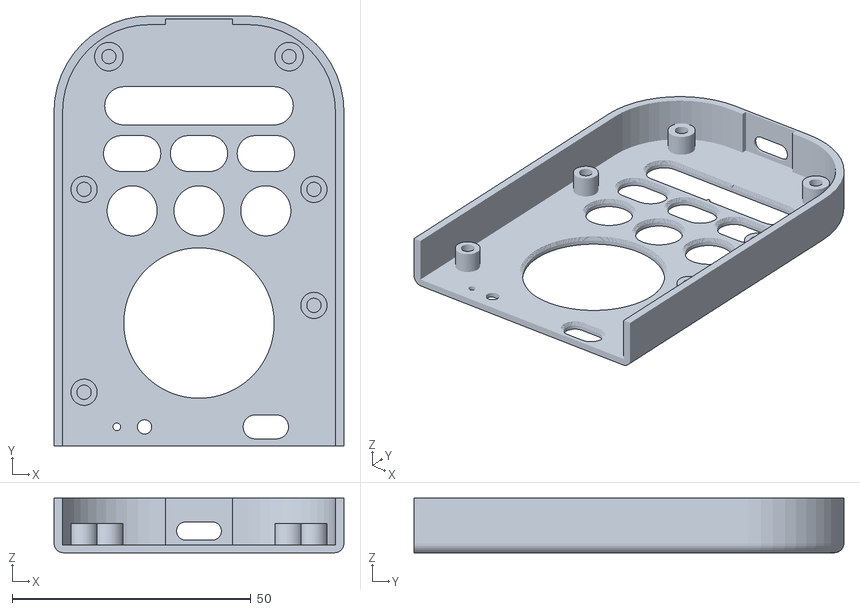
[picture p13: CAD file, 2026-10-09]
hardware/enclosure/stl/fit_test_keys.stl
60.7 x 90.0 x 11.4

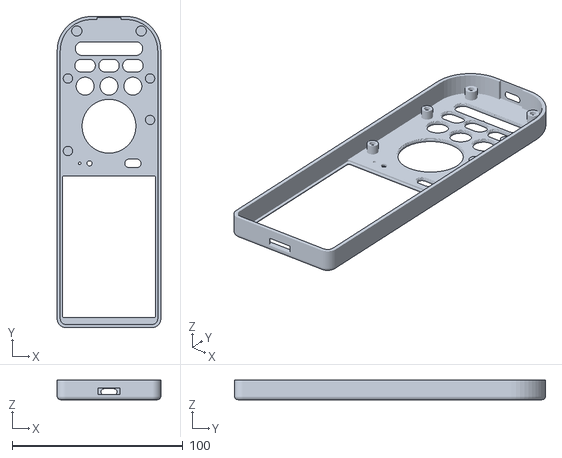
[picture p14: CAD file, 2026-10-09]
hardware/enclosure/stl/front_shell.stl
60.7 x 182.2 x 11.4

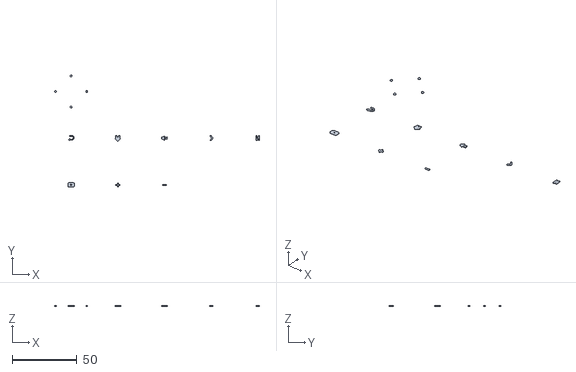
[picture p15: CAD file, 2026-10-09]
hardware/enclosure/stl/caps_labels.stl
158.1 x 86.5 x 0.6

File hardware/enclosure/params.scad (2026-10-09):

// GENERATED by hardware/layout.py -- edit layout.py, not this file.
// Shell coords: x right, y DOWN from the top end, z up from the back face.
W = 60.74;
L = 182.23;
H = 12.95;
WALL = 1.8;
R_TOP = 5;
R_BOT = 20;
FRONT_T = 1.6;
LIP = 0.8;
LIP_OVER = 1.2;
BACK_T = 1.5;
CLEAR = 0.3;
LENS = [56.54, 84.96, 0.3];
LENS_C = [30.37, 47.28];
LENS_Y1 = 89.76;
VA = [49.96, 74.44];
VA_TOP = 3.26;
ACTIVE = [48.96, 73.44];
LCD = [3.09, 6.34, 54.56, 82.84];
LCD_T = 2.1;
CTP_T = 1.65;
PANEL_T = 3.75;
FOAM_T = 1.6;
Z_LENS_TOP = 12.15;
Z_LCD_BOT = 8.4;
Z_FRONT_IN = 11.35;
FPC = [17.62, 25.5, 65.8368, 77.5368, 0.8, 1.425, 8.77, 48, 1.6];
ZIF = [15.87, 66.4868, 29.2, 4.4, 1.5];
BATT = [50, 85, 4];
BATT_C = [30.37, 46.15];
BATT_BAY = [4.55, 3.25, 56.19, 90.16];
BP_INSET = 3.4;
BP_T = 0.8;
Z_BP_TOP = 6.8;
Z_BP_BOT = 6;
BP_LIP_IN = 3.25;
RAILS = [[3.25, 3.25, 4.55, 90.16], [56.19, 3.25, 57.49, 90.16]];
STANDOFFS = [[11.5, 173.73, 6], [49.24, 173.73, 6]];
PILLARS = [[28.87, 106.93, 3], [40.17, 117.93, 3], [30.37, 117.93, 3], [19.37, 117.93, 3], [30.37, 128.93, 3], [44.37, 141.43, 3], [30.37, 141.43, 3], [16.37, 141.43, 3], [44.37, 153.43, 3], [30.37, 153.43, 3], [16.37, 153.43, 3], [40.37, 163.43, 3], [20.37, 163.43, 3]];
BAT_PADS = [[12, 92.46], [16, 92.46]];
KEY_HOLES = [[6.3, 103.43], [54.44, 121.63], [6.3, 145.93], [54.44, 145.93]];
POST_D = 5.5;
Z_ACTUATOR = 8.3;
SW_BODY = 5.1;
SW_HEIGHT = 1.5;
CAP_PROTRUDE = 1.2;
CAP_HOLE_CLR = 0.25;
CAP_FLANGE = 0.6;
KEYS = [["UP", "ring", [30.37, 106.93], 90, ""], ["RIGHT", "ring", [41.37, 117.93], 0, ""], ["OK", "ok", [30.37, 117.93], 0, ""], ["LEFT", "ring", [19.37, 117.93], 180, ""], ["DOWN", "ring", [30.37, 128.93], 270, ""], ["BACK", "round", [44.37, 141.43], 0, "@back"], ["HOME", "round", [30.37, 141.43], 0, "@home"], ["MUTE", "round", [16.37, 141.43], 0, "@mute"], ["PLEX", "pill", [44.37, 153.43], 0, "@plex"], ["NFLX", "pill", [30.37, 153.43], 0, "@netflix"], ["YT", "pill", [16.37, 153.43], 0, "@youtube"], ["VOLUP", "volR", [40.37, 163.43], 0, "+"], ["VOLDN", "volL", [20.37, 163.43], 0, "−"]];
DPAD_C = [30.37, 117.93];
DPAD_ARM = 11;
DPAD_R_OUT = 15.5;
DPAD_R_IN = 8.6;
DPAD_OK_R = 7.4;
DPAD_OK_DROP = 0.6;
DPAD_OK_LIP = 0.4;
DPAD_ISLAND = [5.45, 7.45];
DPAD_BRIDGE_W = 1.2;
ROUND_R = 5;
PILL = [11.5, 7];
VOL_BAR = [39, 7.5];
VOL_SPLIT = 1;
VOL_C = [30.37, 163.43];
PWR_KEY = [44.37, 96.18];
PWR_PILL = [9, 4.5];
MOD = [44.29, 104.08, 25.5, 18, 3.1];
ANT_KEEPOUT = [49.54, 91.58, 57.34, 116.58];
MOTOR_C = [7.8, 128.37];
MOTOR_D = 8;
MOTOR_T = 3.3;
SENSOR_HOLES = [[18.97, 96.18, 3], [13.17, 96.18, 1.6]];
SENSOR_WIN = [16.37, 96.18, 11, 4];
ALS_PIPE_Z0 = 8;
EN_SLOT = [45.49, 117.08, 6.5, 3.2];
TOP_TABS = [[16.37, 8], [44.37, 8]];
PARTS = [[11.4, 113.17, 3, 3, 1.1], [8.2, 121.37, 3, 3, 1], [18.97, 96.94, 7.4, 5, 4], [13.17, 96.18, 2, 2, 0.7], [9.2, 140.43, 2, 2, 0.8], [52.74, 156.37, 4.9, 6, 1.7], [46.59, 103.18, 3, 3, 1.3], [53.24, 131.63, 4, 9, 1.1]];
IR_LED_X = [27.47, 33.27];
IR_LED_TIP_Y = 2.55;
IR_LED_AXIS_Z = 1.2;
IR_LED_PAD_Y = 5.02;
IR_LED_LEN = 2.47;
IR_WINDOW = [30.37, 13, 4, 8];
USB_X = 30.37;
USB_Z = 8.38;
USB_OPEN = [9.4, 3.8];
USB_WALL_T = 0.6;
USB_FACE_Y = 181.53;
USB_TAB = [24.37, 36.37, 180.93];
USB_H = 3.16;
TOP_BOSSES = [];
BOT_BOSSES = [[11.5, 173.73], [49.24, 173.73]];
BOSS_D = 6;
INSERT_HOLE_D = 3;
INSERT_HOLE_DEPTH = 4;
SCREW_CLR_D = 2.4;
SCREW_HEAD_D = 4.2;
BOARD_SCREWS = [[6.3, 103.43], [54.44, 121.63], [6.3, 145.93], [54.44, 145.93]];
PLATE_SCREWS = [[11.5, 173.73], [49.24, 173.73]];
BOARD_HEAD = [4, 1.6];

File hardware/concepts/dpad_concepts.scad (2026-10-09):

// D-pad design concepts for the Bleep remote. Each one uses the same five
// switches (UP/DOWN/LEFT/RIGHT 11 mm from the centre, OK in the middle) and
// sits between the screen (20.8 mm above the D-pad centre) and the row of
// round keys (23.5 mm below), on the real 65.2 mm wide face.
//   openscad -D variant=1 -o ring.png dpad_concepts.scad
variant = 1;
$fn = 96;

W = 65.2;
SHELL = "#34363a";
KEY = "#55585e";
LIGHT = "#e9e6df";
ACCENT = "#5fb3c9";
GAP = "#151618";
P = 1.4;          // how far the caps stand proud of the face

// ---------------------------------------------------------------- context
module face() {
    color(SHELL) translate([0, 0, -3]) linear_extrude(3)
        offset(r = 4) offset(delta = -4) translate([-W / 2, -36]) square([W, 70]);
    // screen (bottom part) and its black border
    color("#0d0e10") translate([-28.27, 20.8, 0]) cube([56.54, 14, 0.25]);
    color("#1d2a33") translate([-24.5, 24.0, 0.26]) cube([49.0, 11, 0.05]);
    // round keys below (BACK / HOME / MUTE)
    for (x = [-14, 0, 14]) translate([x, -23.5, 0]) {
        color(GAP) cylinder(r = 5.4, h = 0.05);
        color(KEY) dome_disc(5.0, P, 0.8);
    }
}

module gap2d(r) { color(GAP) linear_extrude(0.05) children(); }

// a disc with a softly rounded top edge
module dome_disc(r, h, e = 0.6) {
    rotate_extrude() hull() {
        square([r - e, h]);
        square([r, h - e]);
        translate([r - e, h - e]) circle(r = e, $fn = 24);
    }
}

// extrude a 2D shape with a rounded top edge (approximated by stacked insets)
module soft_extrude(h, e = 0.6, steps = 6) {
    linear_extrude(h - e) children();
    for (i = [0:steps - 1]) {
        a = 90 * (i + 1) / steps;
        translate([0, 0, h - e + e * sin(a - 90 / steps)])
            linear_extrude(e * (sin(a) - sin(a - 90 / steps)) + 0.001) offset(delta = -e * (1 - cos(a))) children();
    }
}

module tri2d(s) { polygon([[0, s * 0.6], [-s * 0.55, -s * 0.35], [s * 0.55, -s * 0.35]]); }
module chevron2d(s, t = 0.8) { difference() { tri2d(s); translate([0, -t]) tri2d(s); } }

module ok_text(h, size = 2.6, c = LIGHT) {
    color(c) translate([0, 0, h]) linear_extrude(0.05) text("OK", size = size, font = "Liberation Sans:style=Bold", halign = "center", valign = "center");
}

// ---------------------------------------------------------------- 1. ring (Chromecast / Google TV style)
module v_ring() {
    gap2d() difference() { circle(r = 16.3); circle(r = 7.6); }
    color(KEY) rotate_extrude() hull() {
        translate([8.6, 0]) square([7.2, 0.1]);
        translate([9.2, P - 0.6]) circle(r = 0.6, $fn = 24);
        translate([15.2, P - 0.6]) circle(r = 0.6, $fn = 24);
    }
    // four small dots mark the press points
    for (a = [0:90:270]) rotate(a) translate([12.2, 0, P]) color(LIGHT) cylinder(r = 0.65, h = 0.06);
    color(LIGHT) dome_disc(7.1, P + 0.2, 1.0);
}

// ---------------------------------------------------------------- 2. click wheel (iPod style)
module v_wheel() {
    gap2d() circle(r = 17.6);
    color(LIGHT) difference() {
        dome_disc(17.2, 0.9, 0.5);
        translate([0, 0, -1]) cylinder(r = 7.9, h = 5);
    }
    gap2d() circle(r = 7.9);
    color(LIGHT) dome_disc(7.4, 0.9, 0.5);
    // printed marks: arrows on the wheel, a thin ring on the button
    color("#8a8d93") for (a = [0:90:270]) rotate(a) translate([0, 12.7, 0.9]) linear_extrude(0.05) tri2d(2.4);
    color("#8a8d93") translate([0, 0, 0.9]) linear_extrude(0.05) difference() { circle(r = 5.6); circle(r = 5.2); }
}

// ---------------------------------------------------------------- 3. plus rocker (game pad)
module plus2d() {
    offset(r = 2.0) offset(delta = -2.0) union() {
        square([31, 10.5], center = true);
        square([10.5, 31], center = true);
    }
}
module v_plus() {
    gap2d() offset(delta = 0.5) plus2d();
    color(KEY) difference() {
        soft_extrude(P + 0.4, 0.8) plus2d();
        // shallow dish so the thumb rolls toward the centre
        translate([0, 0, 60 + P - 0.3]) sphere(r = 60, $fn = 160);
        translate([0, 0, -1]) cylinder(r = 5.9, h = 5);
    }
    for (a = [0:90:270]) rotate(a) color(LIGHT) translate([0, 11.6, P + 0.41]) linear_extrude(0.05) tri2d(2.6);
    gap2d() circle(r = 5.9);
    color(ACCENT) dome_disc(5.4, P + 0.2, 0.9);
}

// ---------------------------------------------------------------- 4. petals (four teardrop keys round the OK)
module petal2d() { hull() { translate([0, 12.3]) circle(r = 4.4); translate([0, 7.4]) circle(r = 1.6); } }
module v_petals() {
    for (a = [0:90:270]) rotate(a) {
        gap2d() offset(r = 0.5) petal2d();
        color(KEY) soft_extrude(P + 0.2, 0.9) petal2d();
        color(LIGHT) translate([0, 12.6, P + 0.25]) linear_extrude(0.05) chevron2d(2.6, 0.75);
    }
    gap2d() circle(r = 5.5);
    color(LIGHT) difference() {
        dome_disc(5.0, P + 0.6, 0.8);
        translate([0, 0, 22 + P + 0.2]) sphere(r = 22, $fn = 120);     // dished OK
    }
}

// ---------------------------------------------------------------- 5. squircle pad (Roku style)
module squircle2d(s, r) { offset(r = r) offset(delta = -r) square(s, center = true); }
module v_squircle() {
    gap2d() squircle2d(33.4, 10.5);
    color(KEY) difference() {
        soft_extrude(P, 0.7) squircle2d(32.4, 10);
        translate([0, 0, -1]) linear_extrude(5) squircle2d(14.8, 5);
    }
    for (a = [0:90:270]) rotate(a) color(ACCENT) translate([0, 12.2, P + 0.01]) linear_extrude(0.05) chevron2d(3.0, 0.8);
    gap2d() squircle2d(14.8, 5);
    color(LIGHT) soft_extrude(P + 0.2, 0.7) squircle2d(13.8, 4.6);
    ok_text(P + 0.21, 2.8, "#55585e");
}

// ---------------------------------------------------------------- 6. thumb nub (one tilting cap, press for OK)
module v_nub() {
    // fixed bezel on the face with four direction ticks
    color(SHELL) difference() {
        dome_disc(16.2, 0.8, 0.5);
        translate([0, 0, -1]) cylinder(r = 12.6, h = 5);
    }
    for (a = [0:90:270]) rotate(a) color(ACCENT) translate([0, 14.4, 0.8]) linear_extrude(0.05) square([0.9, 2.2], center = true);
    gap2d() circle(r = 12.6);
    // the nub: a concave thumb pad on a short neck
    color(LIGHT) difference() {
        union() {
            cylinder(r = 9.5, h = 1.0);
            translate([0, 0, 1.0]) cylinder(r1 = 11.6, r2 = 12.0, h = 1.6);
        }
        translate([0, 0, 2.6 + 40 - 0.9]) sphere(r = 40, $fn = 180);
    }
}

// ---------------------------------------------------------------- 7. split ring (four arcs, Apple-TV-like)
module arc2d(a0, a1, r0, r1) {
    intersection() {
        difference() { circle(r = r1); circle(r = r0); }
        polygon([[0, 0], [40 * cos(a0), 40 * sin(a0)], [40 * cos((a0 + a1) / 2), 40 * sin((a0 + a1) / 2)], [40 * cos(a1), 40 * sin(a1)]]);
    }
}
module v_arcs() {
    for (a = [0:90:270]) rotate(a) {
        gap2d() offset(r = 0.5) offset(r = 1) offset(delta = -1) arc2d(52, 128, 8.4, 16.0);
        color(KEY) soft_extrude(P, 0.7) offset(r = 1) offset(delta = -1) arc2d(52, 128, 8.4, 16.0);
        color(ACCENT) translate([0, 12.2, P + 0.01]) linear_extrude(0.05) tri2d(1.8);
    }
    gap2d() circle(r = 7.4);
    color(ACCENT) dome_disc(6.9, P + 0.3, 1.0);
}

// ---------------------------------------------------------------- 0. current design (four ring segments + OK)
module v_current() {
    for (a = [45:90:315]) rotate(a) {
        gap2d() offset(r = 0.5) arc2d(-44.0, 44.0, 7.7, 15.5);
    }
    for (a = [0:90:270]) rotate(a) {
        color(KEY) soft_extrude(P, 0.6) intersection() {
            difference() { circle(r = 15.5); circle(r = 7.7); }
            rotate(45) square(40);
            offset(delta = -0.6) rotate(45) square(40);
        }
        color(LIGHT) translate([11.6, 0, P + 0.01]) linear_extrude(0.05) rotate(-90) tri2d(2.2);
    }
    gap2d() circle(r = 5.7);
    color(KEY) dome_disc(5.2, P, 0.8);
    ok_text(P + 0.01, 2.4);
}

face();
if (variant == 0) v_current();
else if (variant == 1) v_ring();
else if (variant == 2) v_wheel();
else if (variant == 3) v_plus();
else if (variant == 4) v_petals();
else if (variant == 5) v_squircle();
else if (variant == 6) v_nub();
else if (variant == 7) v_arcs();

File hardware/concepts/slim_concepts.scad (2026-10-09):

// Width studies for the Bleep remote (render only, not the production model).
// Everything is laid out from params.scad and re-centred on the new width.
//   style 0: current, 65.2 mm (frame over the glass edge)
//   style 1: trimmed shell, wall + clearance beside the glass (~60.7 mm)
//   style 2: edge-to-edge glass across the full width (~57.4 mm)
//   style 3: like 2, with the screen right up to the top edge; the power key
//            and a sensor window (IR receiver + light sensor) in a row under it
//   style 4: trimmed shell (style 1) with the screen moved up as far as the
//            10 mm top corners allow, power key + sensor window under it
//   style 5: style 4 with 5 mm top corners, so the screen goes ~4 mm higher
//   style 6: trimmed, 5 mm top corners, screen 9.4 mm from the top so the
//            ESP32 antenna stays clear of it; power key + one sensor window
//            stay in the top strip, keys keep today's spacing to the screen
include <../enclosure/params.scad>
style = 0;
$fn = 72;

scheme = "concept";                     // "concept" or "arctic" (the viewer's colourways)
ARC = scheme == "arctic";
SHELL = ARC ? "#ffffff" : "#3a3c41";     // arctic white, lifted to read white under the render lighting
KEY = ARC ? "#b3b7bb" : "#55585e";
LIGHT = "#e9e6df";
ACCENT = "#5fb3c9";
OKC = ARC ? "#5ac4da" : LIGHT;          // OK key
DOT = ARC ? "#18191b" : LIGHT;          // legends (ring dots)
PWRC = ARC ? "#e5612b" : ACCENT;        // power key
GAP = ARC ? "#8a8e93" : "#151618";
GLASS = "#0b0c0e";

W0 = W;
WS = style == 0 ? W0 : (style == 1 || style >= 4) ? LENS[0] + 2 * 0.3 + 2 * 1.8 : LENS[0] + 0.9;
GY0 = style == 3 ? 0.45 : style == 4 ? 8.0 : style == 5 ? 4.0 : style == 6 ? 9.4 : LENS_C[1] - LENS[1] / 2;     // glass top edge
GB = GY0 + LENS[1];                                    // glass bottom edge
ROW = GB + 5.0;                                        // style 3: power key + sensor row
ky = style == 6 ? GY0 - (LENS_C[1] - LENS[1] / 2) : (style >= 3) ? (ROW + 2.25 + 4.0 + 15.5) - 121.56 : 0;   // keys move with the screen
LS = L + ky;
dx = (WS - W0) / 2;                     // re-centre everything on the new width
function P(p) = [p[0] + dx, -p[1]];
function PK(p) = P([p[0], p[1] + ky]);                 // key area (below the screen)
RT = style == 3 ? 0.6 : style == 2 ? 6 : style >= 5 ? 5 : R_TOP;      // style 3: square top end to match the rectangular glass            // tighter top corners when the glass runs edge to edge

module outline2d() {
    hull() {
        translate([RT, -RT]) circle(r = RT);
        translate([WS - RT, -RT]) circle(r = RT);
        translate([R_BOT, -LS + R_BOT]) circle(r = R_BOT);
        translate([WS - R_BOT, -LS + R_BOT]) circle(r = R_BOT);
    }
}

// body with a soft top edge
module body() {
    e = 1.6;
    color(SHELL) {
        linear_extrude(H - e) outline2d();
        for (i = [0:7]) {
            a = 90 * (i + 1) / 8;
            translate([0, 0, H - e + e * sin(a - 90 / 8)]) linear_extrude(e * (sin(a) - sin(a - 90 / 8)) + 0.01)
                offset(delta = -e * (1 - cos(a))) outline2d();
        }
    }
}

// the touch glass is a plain rectangle (0.3 mm corner radius)
module glass2d(grow = 0) {
    translate([(WS - LENS[0]) / 2 - grow, -GB - grow]) offset(r = LENS[2] + grow) offset(delta = -LENS[2])
        square([LENS[0], LENS[1]]);
}
module glass() {
    c = [WS / 2, -(GY0 + LENS[1] / 2)];
    edge = style == 2 || style == 3;
    gw = edge ? WS - 0.9 : LENS[0];
    top = edge ? H + 0.2 : Z_LENS_TOP;
    // glass, black print, then the active area with a hint of the UI
    translate([c[0], c[1], top - 0.6]) {
        if (edge) color(GLASS) translate([-c[0], -c[1], 0]) linear_extrude(0.6) glass2d();
        else color(GLASS) linear_extrude(0.6) offset(r = 0.6) square([gw - 1.2, LENS[1] - 1.2], center = true);
        aa_y = LENS[1] / 2 - VA_TOP - 0.5 - ACTIVE[1] / 2;
        translate([0, aa_y, 0.6]) {
            color("#1b2530") linear_extrude(0.02) square(ACTIVE, center = true);
            color("#2b3846") for (r = [0:2], col = [0:1]) translate([-11.5 + col * 23, 22 - r * 17, 0.02]) linear_extrude(0.02) offset(r = 2) square([17, 11], center = true);
            color(ACCENT) translate([-11.5, 22, 0.04]) linear_extrude(0.02) offset(r = 2) square([17, 11], center = true);
            color("#7f8a96") translate([0, -31, 0.02]) linear_extrude(0.02) offset(r = 1) square([40, 4], center = true);
        }
    }
    if (!edge) color(GAP) translate([c[0], c[1], Z_LENS_TOP - 0.02]) linear_extrude(H - Z_LENS_TOP + 0.03)
        difference() { square([LENS[0] - 2 * LIP_OVER + 1.0, LENS[1] - 2 * LIP_OVER + 1.0], center = true);
                       square([LENS[0] - 2 * LIP_OVER, LENS[1] - 2 * LIP_OVER], center = true); }
}

module key(h = CAP_PROTRUDE) { translate([0, 0, H - 0.3]) linear_extrude(h + 0.3) children(); }
module gap(d = 0.45) { color(GAP) translate([0, 0, H - 0.05]) linear_extrude(0.1) offset(delta = d) children(); }
module pill2d(w, h) { hull() for (s = [-1, 1]) translate([s * (w / 2 - h / 2), 0]) circle(d = h); }

module keys() {
    dp = PK([32.6, 121.56]);
    translate(dp) {
        gap() circle(r = 15.5);
        color(KEY) key() difference() { circle(r = 15.5); circle(r = 8.6); }
        for (a = [0:90:270]) rotate(a) color(DOT) translate([12.05, 0, H + CAP_PROTRUDE]) cylinder(r = 0.75, h = 0.05);
        color(OKC) key(CAP_PROTRUDE + 0.2) circle(r = 7.4);
    }
    for (x = [18.6, 32.6, 46.6]) translate(PK([x, 145.06])) { gap() circle(r = ROUND_R); color(KEY) key() circle(r = ROUND_R); }
    for (x = [18.6, 32.6, 46.6]) translate(PK([x, 157.06])) { gap() pill2d(PILL[0], PILL[1]); color(KEY) key() pill2d(PILL[0], PILL[1]); }
    translate(PK(VOL_C)) {
        gap() pill2d(VOL_BAR[0], VOL_BAR[1]);
        color(KEY) key() difference() { pill2d(VOL_BAR[0], VOL_BAR[1]); square([1.0, 20], center = true); }
    }
    pw = style == 6 ? [49.0, 6.2] : style >= 3 ? [46.6, ROW] : [49.0, 9.5];
    translate(P(pw)) { gap() pill2d(PWR_PILL[0], PWR_PILL[1]); color(PWRC) key() pill2d(PWR_PILL[0], PWR_PILL[1]); }
    if (style >= 3) {
        // one smoked window over the IR receiver and the light sensor
        translate(P(style == 6 ? [16.2, 6.2] : [18.6, ROW])) {
            color(GAP) translate([0, 0, H - 0.05]) linear_extrude(0.1) offset(delta = 0.3) pill2d(11.0, 4.0);
            color("#1c1f24") translate([0, 0, H - 0.04]) linear_extrude(0.1) pill2d(11.0, 4.0);
            color("#3a4450") translate([2.6, 0, H + 0.07]) cylinder(d = 2.8, h = 0.01);
            color("#3a4450") translate([-3.2, 0, H + 0.07]) cylinder(d = 1.4, h = 0.01);
        }
    } else
        for (s = SENSOR_HOLES) color(GAP) translate([P(s)[0], P(s)[1], H - 0.05]) cylinder(d = s[2], h = 0.1);
}

difference() {
    body();
    // screen window through the front frame (the frame overlaps the glass by LIP_OVER)
    if (style < 2 || style >= 4) { c = [WS / 2, -(GY0 + LENS[1] / 2)]; translate([c[0], c[1], Z_LENS_TOP - 0.01])
        linear_extrude(H) offset(r = 0.8) square([LENS[0] - 2 * LIP_OVER - 1.6, LENS[1] - 2 * LIP_OVER - 1.6], center = true); }
    // edge-to-edge: the glass sits in a shallow pocket across the full width
    if (style == 2 || style == 3) translate([0, 0, H - 0.4]) linear_extrude(2) glass2d(0.25);
}
glass();
keys();

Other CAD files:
hardware/enclosure/remote.scad

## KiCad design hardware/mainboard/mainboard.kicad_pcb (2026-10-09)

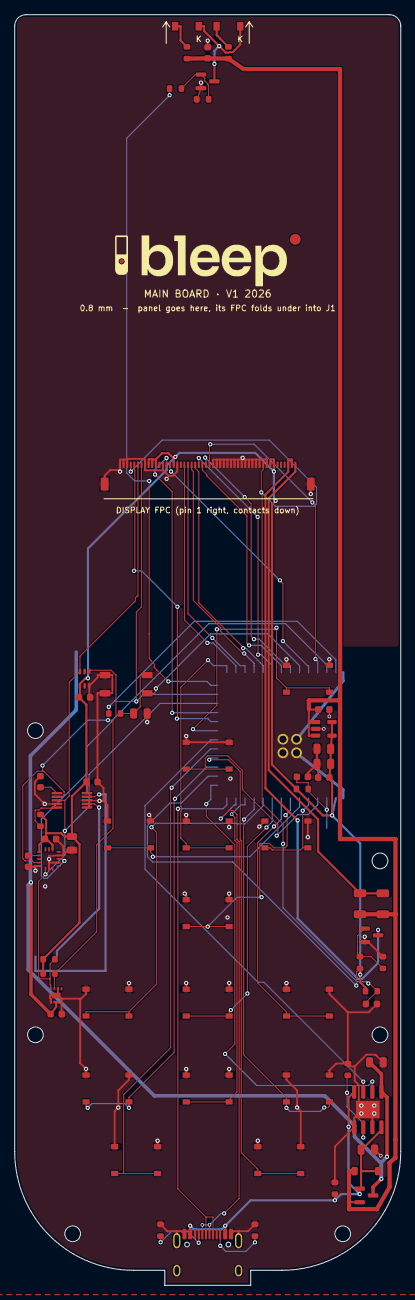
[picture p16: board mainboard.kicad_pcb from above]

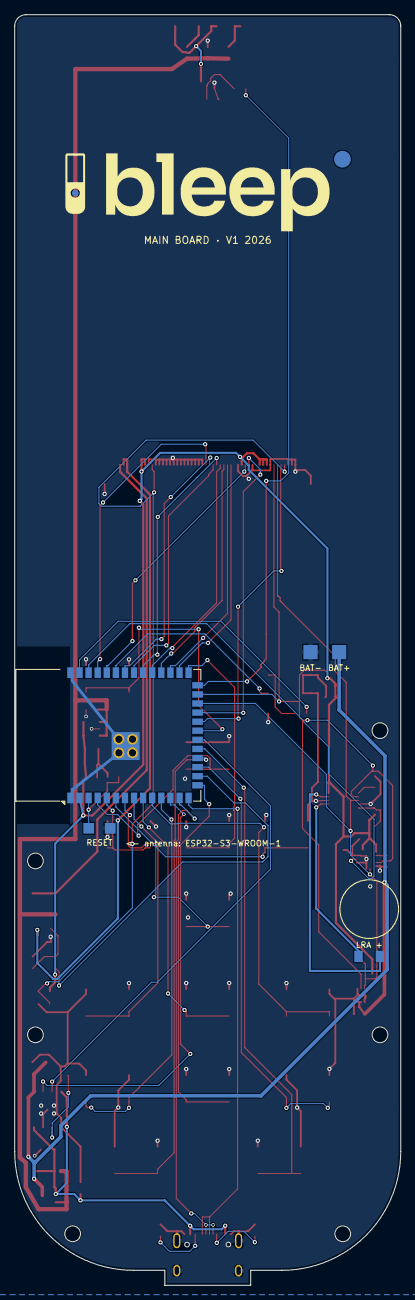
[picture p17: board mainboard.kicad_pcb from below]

Board: 2 copper layers, 53.9 x 177.5 mm, 80 parts (8 on the bottom side), 59 nets.

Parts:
C1: 22uF; C_0805_2012Metric
C2, C9, C13: 100nF; C_0603_1608Metric
C3, C4, C7, C8, C15, C17, C18: 1uF; C_0603_1608Metric
C5, C11, C12, C14, C16: 10uF; C_0805_2012Metric
C6: 10uF; C_0603_1608Metric
D1, D2: VSMB2948SL; VSMB2948SL_SideView
D3: B5819W; D_SOD-123
H1, H2, H3, H4, H5, H6: M2; MountingHole_2.2mm_M2
J1: FPC-05F-50PH15
J3: TYPE-C 16PIN 2MD(073); USB_C_Receptacle_HRO_TYPE-C-31-M-12
LOGO_BACK1, LOGO_BACK2: logo LED dot
LOGO_FRONT1, LOGO_FRONT2: logo LED dot
M1: LRA 0832 (8 mm coin, wired); LRA_8mm_WirePads
Q1, Q2: AO3400A; SOT-23
Q3: AO3401A; SOT-23
R1, R10: 10k; R_0603_1608Metric
R2, R3: 22R; R_0603_1608Metric
R4, R8: 100R; R_0603_1608Metric
R5, R9, R11, R19: 100k; R_0603_1608Metric
R6, R7: 22R; R_1206_3216Metric
R12, R13: 4.7k; R_0603_1608Metric
R16: 3.3k; R_0603_1608Metric
R17, R18: 5.1k; R_0603_1608Metric
R20: 220R; R_0603_1608Metric
SW1, SW2, SW3, SW4, SW5, SW6, SW7, SW8, SW9, SW10, SW11, SW12, SW13, SW14: TS-1187A-B-A-B; SW_Push_1P1T_XKB_TS-1187A
TP1, TP2: battery lead pad; TestPoint_Pad_2.0x2.0mm
TP3, TP4: reset pad; TestPoint_Pad_1.5x1.5mm
U1: ESP32-S3-WROOM-1-N8R2; ESP32-S3-WROOM-1
U2: ME6211C33M5G-N; SOT-23-5
U3: DRV2605LDGST; MSOP-10_3x3mm_P0.5mm
U4: MMA8452QR1; MMA8452Q_QFN-16_3x3mm_P0.5mm
U5: TP4056; SOIC-8-1EP_3.9x4.9mm_P1.27mm_EP2.41x3.3mm
U6: IRM-H638T/TR2; IRM-H638T
U7: LTR-303ALS-01
U8: MAX17048G+T10; MAX17048_TDFN-8_2x2mm

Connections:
3V3: C1.2, C2.2, C5.2, C8.1, C9.1, C14.2, C17.1, J1.9, J1.10, J1.11, J1.16, J1.43, J1.44, R1.1, R10.1, R11.2, R12.1, R13.1, U1.2, U2.4, U2.5, U3.10, U4.1, U4.14, U7.1
ACC_BYP: C13.2, U4.2
ACC_INT: U1.38, U4.11
BL_A: J1.50, R6.2, R7.2
BL_G: Q2.1, R8.2, R9.1
BL_K: J1.48, J1.49, Q2.3
BL_PWM: R8.1, U1.16
CC1: J3.A5, R17.1
CC2: J3.B5, R18.1
CHRG: U1.20, U5.7
DRV_EN: R11.1, U3.5
DRV_REG: C7.1, U3.1
EN: C3.1, R1.2, TP3.1, U1.3
GND: C1.1, C2.1, C3.2, C4.2, C5.1, C6.2, C7.2, C8.2, C9.2, C11.2, C12.2, C13.1, C14.1, C15.2, C16.2, C17.2, C18.2, J1.1, J1.2, J1.3, J1.8, J1.13, J1.17, J1.27, J1.28, J1.29, J1.30, J1.31, J1.32, J1.33, J1.34, J1.35, J1.36, J1.37, J1.38, J1.39, J1.40, J1.42, J1.51, J1.52, J3.A1, J3.A12, J3.B1, J3.B12, J3.SH, Q1.2, Q2.2, R5.1, R9.2, R16.2, R17.2, R18.2, R19.2, SW1.1, SW2.1, SW3.1, SW4.1, SW5.1, SW6.1, SW7.1, SW8.1, SW9.1, SW10.1, SW11.1, SW12.1, SW13.1, SW14.1, TP2.1, TP4.1, U1.1, U1.40, U1.41, U2.2, U3.4, U3.8, U4.5, U4.7, U4.10, U4.12, U5.1, U5.3, U5.9, U6.1, U6.2, U7.3, U8.1, U8.4, U8.6, U8.9
IRRX_PWR: R20.1, U1.39
IRRX_V: C16.1, R20.2, U6.4
IR_G: Q1.1, R4.2, R5.2
IR_RX: U1.35, U6.3
IR_TX: R4.1, U1.26
K_BACK: SW6.2, U1.8
K_DOWN: SW5.2, U1.7
K_HOME: SW7.2, U1.9
K_LEFT: SW4.2, U1.6
K_MUTE: SW8.2, U1.10
K_NFLX: SW10.2, U1.12
K_OK: SW3.2, U1.27
K_PLEX: SW9.2, U1.11
K_PWR: SW14.2, U1.21
K_RIGHT: SW2.2, U1.5
K_UP: SW1.2, U1.4
K_VOLDN: SW13.2, U1.19
K_VOLUP: SW12.2, U1.18
K_YT: SW11.2, U1.17
LCD_D0: J1.19, U1.28
LCD_D1: J1.20, U1.29
LCD_D2: J1.21, U1.30
LCD_D3: J1.22, U1.31
LCD_D4: J1.23, U1.32
LCD_D5: J1.24, U1.33
LCD_D6: J1.25, U1.34
LCD_D7: J1.26, U1.37
LCD_DC: J1.14, U1.23
LCD_RST: C15.1, J1.4, J1.41, R10.2
LCD_WR: J1.15, U1.36
LED1_A: D1.2, R2.2
LED2_A: D2.2, R3.2
LED_K: D1.1, D2.1, Q1.3
MOT_N: M1.2, U3.9
MOT_P: M1.1, U3.7
PROG: R16.1, U5.2
SCL: J1.7, R13.2, U1.25, U3.2, U4.4, U7.4, U8.7
SDA: J1.6, R12.2, U1.24, U3.3, U4.6, U7.6, U8.8
STDBY: U1.15, U5.6
TP_INT: J1.5, U1.22
USB_DN: J3.A7, J3.B7, U1.13
USB_DP: J3.A6, J3.B6, U1.14
VBAT: C12.1, C18.1, Q3.3, TP1.1, U5.5, U8.2, U8.3
VBUS: C11.1, D3.2, J3.A4, J3.A9, J3.B4, J3.B9, Q3.1, R19.1, U5.4, U5.8
VSYS: C4.1, C6.1, D3.1, Q3.2, R2.1, R3.1, R6.1, R7.1, U2.1, U2.3

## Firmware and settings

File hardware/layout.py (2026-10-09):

"""Shared mechanical layout for Bleep, the touch remote, v1 (own ESP32 + bare display).

Bleep is design 1b "Pebble", built around ONE main board of our own. Slim: the shell
is only wall + clearance wider than the touch glass, the glass runs up to
4.8 mm from the top end (5 mm top corners), and the power key and the sensor
window sit in a row under the screen.

  top side    (JLCPCB Economic assembly): key switches, USB-C, charger, LDO,
              haptics driver, accelerometer, IR LEDs, backlight driver
  top side    (JLCPCB too): a 50-pin 0.5 mm ZIF connector UNDER the panel;
              the display's FPC folds back under the LCD and plugs into it
  underside   (you solder): ESP32-S3-WROOM-1 module, lying across the board
              under the top of the key area with its antenna at the RIGHT
              edge (the panel would detune it anywhere under the screen),
              battery leads, vibration-motor leads
  battery     flat cell under the SCREEN, in a tub in the back plate

The display is BuyDisplay's ER-TFT035IPS-6 (3.5" IPS 320x480, ILI9488) with
its ER-TPC035-6 capacitive touch panel (FT6236): one 50-pin plug-in FPC carries
the LCD (8080 8-bit parallel) and the touch I2C.

Coordinate systems (all mm):
  shell : origin at the outer top-left corner of the shell seen from the
          front, x to the right, y DOWN towards the USB-C end,
          z UP from the outer back face (z = 0) to the front face (z = H).
          The main board uses these x/y coordinates directly (seen from its
          top side, which faces the front).
  keys  : the key layout's own origin (KEYS_X0, KEYS_Y0 in shell coords).
  panel : origin at the top-left corner of the touch glass seen from the
          front (FPC edge at the bottom), x right, y down.

Run `python layout.py` to regenerate enclosure/params.scad and run the fit
checks. The KiCad generator (mainboard/gen_mainboard.py) imports this module.
"""

import math
import os

# ---------------------------------------------------------------------------
# Display: BuyDisplay ER-TFT035IPS-6 + ER-TPC035-6 (datasheet in docs/).
# Panel coords: origin at the touch glass's top-left corner seen from the
# front, FPC edge at the bottom.  VERIFY THE FPC FOLD ON THE REAL PANEL.
# ---------------------------------------------------------------------------
LENS_W, LENS_H, LENS_R = 56.54, 84.96, 0.3      # touch glass (CTP O.D.)
LCD_W, LCD_H = 54.56, 82.84                      # LCD / backlight outline (BL O.D.)
LCD_X0, LCD_Y0 = 0.99, 1.54                      # glass corner -> LCD corner (the FPC end has 0.58)
LCD_T = 2.1                                      # LCD alone
PANEL_T = 3.75                                   # LCD + touch glass (datasheet 3.75 +-0.25)
CTP_T = PANEL_T - LCD_T
VA = (49.96, 74.44)                              # touch glass viewing area
VA_TOP = 3.26
ACTIVE_W, ACTIVE_H = 48.96, 73.44                # LCD active area, centred across
ACTIVE_TOP = 3.76
# The 50-pin FPC (0.5 mm, 25.5 mm wide, centred) leaves the panel's bottom edge
# and reaches 30 mm past the glass edge. It folds 180 deg back under the LCD into
# a bottom-contact ZIF connector on the main board. Pin 1 ends up on the right
# (seen from the front). Its parts area (<= 1.5 mm thick) lies under the LCD too.
FPC_LEN = 30.0
FPC_W = 25.5
FPC_PARTS = 18.3                                 # parts area from the glass edge, along the FPC
# Only the first 3.9 mm of the FPC are narrow flexible necks; then comes a wide
# section (~48 mm, measured off the drawing, centred ~2.4 mm towards pin 1 / +x)
# with a strip of parts 4.9-7.0 mm out. How much cable the real fold uses is
# uncertain by ~+-1.5 mm, so J1 sits FPC_SLACK closer to the fold than the
# nominal fold needs: a looser fold still reaches fully into J1, and a tighter
# one bottoms out in J1 and makes the fold bulge outward by about half the excess.
FPC_WIDE_W, FPC_WIDE_DX = 48.0, 2.4
FPC_SLACK = 1.6
ZIF_H = 1.5                                      # XUNPU FPC-05F-50PH15 height
FOAM_T = ZIF_H + 0.1                             # gap under the LCD (foam pads at the top end)

# ---------------------------------------------------------------------------
# ESP32-S3-WROOM-1-N8R2 (18 x 25.5 x 3.1), soldered by hand on the UNDERSIDE,
# PCB antenna end at the board's top edge
# ---------------------------------------------------------------------------
MOD_W, MOD_L, MOD_T = 18.0, 25.5, 3.1
MOD_ANT_L = 6.0                                  # antenna part at the top end

# ---------------------------------------------------------------------------
# Shell
# ---------------------------------------------------------------------------
WALL = 1.8           # side/end wall thickness
CLEAR = 0.3          # clearance around the touch glass
FRONT_T = 1.6        # front wall thickness (key area)
LIP = 0.8            # front frame over the glass
LIP_OVER = 1.2       # how far the frame overlaps the glass edge
BACK_T = 1.5         # back plate thickness
SWELL = 0.5          # Li-Po swell gap
# Flat cell under the SCREEN, on the flat back plate, pushed to the top end
# (away from the antenna). Any cell up to BATT_BAY fits; set its size here
# (corner guides on the plate locate it; its thickness drives H).
BATT = (50.0, 85.0, 4.0)   # (x, y, z): a 405085, 4 x 50 x 85 mm
BP_T = 0.8                 # main board thickness

LENS_TOP = 4.8       # outer top edge -> glass top edge (keeps the LCD 0.7 mm clear of the IR LEDs' backs)
BOTTOM_ZONE = 11.0   # key area -> inner bottom wall: USB-C socket
R_TOP = 5.0
R_BOT = 20.0

KEYS_W, KEYS_H = 61.0, 70.0                      # key grid extent
W = LENS_W + 2 * CLEAR + 2 * WALL                # the glass sets the width: wall + clearance each side

# z stack (from the outer back face)
Z_BP_BOT = BACK_T + SWELL + BATT[2]
Z_BP_TOP = Z_BP_BOT + BP_T
Z_LCD_BOT = Z_BP_TOP + FOAM_T
Z_LCD_TOP = Z_LCD_BOT + LCD_T
Z_LENS_TOP = Z_LCD_BOT + PANEL_T
H = Z_LENS_TOP + LIP
Z_FRONT_IN = H - FRONT_T     # inner face of the front wall in the key area

# glass placement
LENS_X0 = (W - LENS_W) / 2
LENS_Y0 = LENS_TOP
LENS_CX = W / 2
LENS_CY = LENS_Y0 + LENS_H / 2
LENS_Y1 = LENS_Y0 + LENS_H                       # bottom (FPC) edge
# FPC fold: out past the glass edge, a U-bend down to the connector's entry
# height, then back under the LCD
FPC_OUT = 0.8
FPC_BEND_R = (Z_LCD_TOP - 0.1 - (Z_BP_TOP + 0.75)) / 2
FPC_FOLD_END = FPC_LEN - 2 * FPC_OUT - math.pi * FPC_BEND_R      # FPC end, measured back from the glass edge
FPC_END_Y = LENS_Y1 - FPC_FOLD_END
FPC_PARTS_Y = LENS_Y1 - (FPC_PARTS - 2 * FPC_OUT - math.pi * FPC_BEND_R)   # far end of the parts area


def panel_to_shell(px, py):
    return (LENS_X0 + px, LENS_Y0 + py)


# ---------------------------------------------------------------------------
# Main board
# ---------------------------------------------------------------------------
BP_INSET = WALL + 1.6        # outline = shell outline inset by this (clears the back-plate lip)


SW_PART = "TS-1187A-B-A-B"
SW_FOOTPRINT = ("Button_Switch_SMD", "SW_Push_1P1T_XKB_TS-1187A")
SW_HEIGHT = 1.5
SW_BODY = 5.1

CAP_PROTRUDE = 1.2
CAP_HOLE_CLR = 0.25
CAP_FLANGE = 0.6
Z_ACTUATOR = Z_BP_TOP + SW_HEIGHT
STEM_LEN = Z_FRONT_IN - CAP_FLANGE - Z_ACTUATOR

DPAD_C = (30.5, 18.5)
DPAD_ARM = 11.0
DPAD_R_OUT = 15.5
# D-pad: one-piece ring that rocks onto the four direction switches (concept 1,
# Chromecast-style), with a large OK button in its middle. The ring is held by
# its flange under the front shell; the OK's flange sits DPAD_OK_DROP below the
# ring's inner edge, so the ring holds the OK in without pressing it when it tilts.
DPAD_R_IN = 8.6
DPAD_OK_R = 7.4
DPAD_OK_DROP = 0.6
DPAD_OK_LIP = 0.4
DPAD_ISLAND = (5.45, 7.45)
DPAD_BRIDGE_W = 1.2
ROW2_Y, APPS_Y, VOL_Y = 42.0, 54.0, 64.0
COLS = (16.5, 30.5, 44.5)
ROUND_R = 5.0
PILL = (11.5, 7.0)
VOL_BAR = (39.0, 7.5)
VOL_SPLIT = 1.0

# The row under the screen (power key + sensor window) sits just past the
# folded FPC; the D-pad follows 4 mm below it. KEYS_X0/KEYS_Y0 place the key
# grid (in its own coords) centred under the screen.
FOLD_OUT = LENS_Y1 + FPC_OUT + FPC_BEND_R + 0.15 + FPC_SLACK / 2   # outer edge of the fold, bulged
ROW_Y = round(FOLD_OUT + 0.5 + SW_BODY / 2 + 0.2, 2)             # power key + sensor row
PWR_PILL = (9.0, 4.5)
KEYS_X0 = W / 2 - DPAD_C[0]
KEYS_Y0 = round(ROW_Y + PWR_PILL[1] / 2 + 4.0 + DPAD_R_OUT - DPAD_C[1], 2)
L = KEYS_Y0 + KEYS_H + BOTTOM_ZONE + WALL   # overall length

# name, switch centre (keys coords), ESP32 GPIO, cap type, cap params, label.
# Every key is on an RTC GPIO, so any key wakes the remote from deep sleep.
# OK is GPIO0: hold it while plugging in USB / resetting to force download mode.
KEYS = [
    ("UP",    (DPAD_C[0], DPAD_C[1] - DPAD_ARM), "IO4",  "ring", 90,  ""),
    ("RIGHT", (DPAD_C[0] + DPAD_ARM, DPAD_C[1]), "IO5",  "ring", 0,   ""),
    ("OK",    DPAD_C,                            "IO0",  "ok",   0,   ""),
    ("LEFT",  (DPAD_C[0] - DPAD_ARM, DPAD_C[1]), "IO6",  "ring", 180, ""),
    ("DOWN",  (DPAD_C[0], DPAD_C[1] + DPAD_ARM), "IO7",  "ring", 270, ""),
    ("BACK",  (COLS[2], ROW2_Y),                 "IO15", "round", 0,  "@back"),
    ("HOME",  (COLS[1], ROW2_Y),                 "IO16", "round", 0,  "@home"),
    ("MUTE",  (COLS[0], ROW2_Y),                 "IO17", "round", 0,  "@mute"),
    ("PLEX",  (COLS[2], APPS_Y),                 "IO18", "pill", 0,   "@plex"),
    ("NFLX",  (COLS[1], APPS_Y),                 "IO8",  "pill", 0,   "@netflix"),
    ("YT",    (COLS[0], APPS_Y),                 "IO9",  "pill", 0,   "@youtube"),
    ("VOLUP", (DPAD_C[0] + 10.0, VOL_Y),         "IO10", "volR", 0,   "+"),
    ("VOLDN", (DPAD_C[0] - 10.0, VOL_Y),         "IO11", "volL", 0,   "−"),
]
# PWR key under the screen, in line with the right key column (sleep / wake)
PWR_KEY = (KEYS_X0 + COLS[2], ROW_Y)
PWR_GPIO = "IO13"

# ESP32-S3 pin map (everything not on a key). Strapping pins: IO45 and IO46
# must be low at boot -- both drive MOSFET gates that have pull-downs.
GPIO = {
    "IRRX_PWR": "IO1",     # powers the IR receiver (on only while learning; the fuel gauge reads the cell)
    "ACC_INT": "IO2",      # MMA8452Q INT1: lift-to-wake (RTC)
    "TP_INT": "IO14",      # FT6336U INT: wake on touch (RTC)
    "CHRG": "IO12",        # TP4056 CHRG, low while charging (RTC: wake on plug-in)
    "STDBY": "IO3",        # TP4056 STDBY, low when full (IO3 straps nothing unless an eFuse says so)
    # LCD, 8080 8-bit parallel (ILI9488 IM2..0 = 011, CS tied low, RD high).
    # WR on IO44 (UART0 RX, quiet at boot); D7 on IO43 (UART0 TX: boot
    # chatter there is harmless while WR stays high). Use the USB console.
    "LCD_D0": "IO35", "LCD_D1": "IO36", "LCD_D2": "IO37", "LCD_D3": "IO38",
    "LCD_D4": "IO39", "LCD_D5": "IO40", "LCD_D6": "IO41", "LCD_D7": "IO43",
    "LCD_WR": "IO44", "LCD_DC": "IO21",
    "IR_RX": "IO42",       # IR receiver (learning); the LCD + touch reset is an RC power-on reset
    # IO45 / IO46 must be low at boot: both drive MOSFET gates with pull-downs.
    # The ESP32 lies across the board, so which pin faces which way picks them.
    "BL_PWM": "IO46",
    "IR_TX": "IO45",
    "SDA": "IO47", "SCL": "IO48",
    "USB_DN": "IO19", "USB_DP": "IO20",
}
I2C_ADDR = {"FT6236": 0x38, "DRV2605L": 0x5A, "MMA8452Q": 0x1C}

# Screw points: front-shell posts / bosses with heat-set inserts. The main
# board screws straight onto the four key-area posts (KEY_HOLES) with short M2
# screws from its underside, before the back plate goes on. The back plate is
# held by just the two bottom screws (BOT_BOSSES, through the board into the
# bottom bosses) and, at the top end, where there is no room for bosses beside
# or above the glass, by two snap fingers under the top wall (TOP_TABS). The
# upper right post keeps clear of the antenna.
POST_X = 6.3
KEY_HOLES = [(POST_X, KEYS_Y0 + 4.0), (W - POST_X, KEYS_Y0 + 22.2),
             (POST_X, KEYS_Y0 + 46.5), (W - POST_X, KEYS_Y0 + 46.5)]
POST_D = 5.5
TOP_BOSSES = []
BOT_BOSSES = [(11.5, L - 8.5), (W - 11.5, L - 8.5)]
TOP_TABS = [(W / 2 - 14.0, 8.0), (W / 2 + 14.0, 8.0)]   # back-plate hooks: centre x, width
BOSS_D = 6.0
INSERT_HOLE_D = 3.0
INSERT_HOLE_DEPTH = 4.0
SCREW_CLR_D = 2.4
SCREW_HEAD_D = 4.2
BOARD_SCREWS = KEY_HOLES                         # board -> post, M2 from the board's underside
PLATE_SCREWS = TOP_BOSSES + BOT_BOSSES           # back plate -> board -> boss, the only screws in the plate
BOARD_HEAD = (4.0, 1.6)                          # M2 pan head (ISO 7045): diameter, height under the board

# ---- parts on the main board (shell coords) --------------------------------
# ESP32 module on the underside, lying across the board (rotated 90 deg) just
# below the folded FPC, antenna end 0.3 mm inside the board's RIGHT edge
MOD_TOP = round(ROW_Y - 1.1, 2)
MOD_C = (W - BP_INSET - 0.3 - MOD_L / 2, MOD_TOP + MOD_W / 2)
ANT_SIDE = 3.5                                   # keep-out past the module's long sides
ANT_KEEPOUT = (MOD_C[0] + MOD_L / 2 - MOD_ANT_L - 1.5, MOD_TOP - ANT_SIDE, W - BP_INSET,
               MOD_TOP + MOD_W + ANT_SIDE)       # no copper on either layer (x0, y0, x1, y1)
# Two Vishay VSMB2948SL side-view IR LEDs at the top edge, centred
IR_LED_X = (W / 2 - 2.9, W / 2 + 2.9)
IR_LED_AXIS_Z = 1.2
IR_LED_TIP_Y = WALL + 0.75                       # their bodies end just short of the LCD
IR_LED_LEN = 2.47
IR_LED_PAD_Y = IR_LED_TIP_Y + IR_LED_LEN
IR_LED_BACK_Y = IR_LED_PAD_Y + 0.6               # back of the body (and of its pads)
# Sensors on the top side, under one dark pill-shaped window in the row under
# the screen (in line with the left key column): the IR receiver for learning
# codes (Everlight IRM-H638T, 5 x 4 x 4 mm, lens 0.76 mm towards the top edge)
# and the ambient light sensor (LTR-303ALS-01, 2 x 2 x 0.7 mm). The fuel gauge
# (MAX17048) sits in the left strip.
SENSOR_WIN = (KEYS_X0 + COLS[0], ROW_Y, 11.0, 4.0)          # centre x, y, w, h
IRRX_LENS = (SENSOR_WIN[0] + 2.6, ROW_Y)
IRRX_POS = (IRRX_LENS[0], IRRX_LENS[1] + 0.76)
ALS_POS = (SENSOR_WIN[0] - 3.2, ROW_Y)
SENSOR_HOLES = [(IRRX_LENS[0], IRRX_LENS[1], 3.0), (ALS_POS[0], ALS_POS[1], 1.6)]   # x, y, diameter
ALS_H = 0.7
# Both windows are printed in translucent PETG. The plug in the light sensor's hole
# runs on down as a light pipe and ends this high, 0.5 mm above the sensor
# (through the bare 1.6 mm hole alone it would see only about +-8 deg).
ALS_PIPE_Z0 = Z_BP_TOP + ALS_H + 0.5
FG_POS = (9.2, KEYS_Y0 + 41.0)
# EN + GND pads on the underside (short them to reset the ESP32), reached
# through a slot in the back plate: EN just below the module's EN pin, GND
# to its left (away from the antenna)
EN_PADS = [(MOD_C[0] + 2.7, MOD_TOP + MOD_W + 4.0), (MOD_C[0] - 0.3, MOD_TOP + MOD_W + 4.0)]
EN_SLOT = (MOD_C[0] + 1.2, MOD_TOP + MOD_W + 4.0, 6.5, 3.2)        # centre x, y, length, width
IR_WINDOW = dict(x=sum(IR_LED_X) / 2, w=13.0, h=4.0, zc=Z_BP_TOP + IR_LED_AXIS_Z)
# ZIF connector under the panel: centred on the FPC, opening towards the
# panel's bottom edge; the FPC end sits ~0.2 mm in front of the footprint
# origin (pad row behind it)
ZIF_C = (LENS_X0 + LENS_W / 2, FPC_END_Y + 0.2 + FPC_SLACK)
ZIF_BODY = (-14.5, -1.15, 14.7, 3.25)            # footprint coords (x0, y0, x1, y1), opening at +y

DRV_POS = (11.4, KEYS_Y0 + 13.74)            # DRV2605L MSOP-10 (left strip)
ACC_POS = (8.2, KEYS_Y0 + 21.94)            # MMA8452Q QFN-16 3x3 (Economic-assembly OK)
MOTOR_C = (7.8, KEYS_Y0 + 28.94)            # 8 mm coin LRA, UNDERSIDE (left strip)
MOTOR_D, MOTOR_T = 8.0, 3.3
MOTOR_PADS_Y = MOTOR_C[1] + 6.6             # its two wire pads (x +-1.5, 1.2 x 1.6 mm) below it
CHG_POS = (W - 8.0, KEYS_Y0 + 56.94)        # TP4056 ESOP-8 (right strip)
LDO_POS = (MOD_C[0] + 2.3, MOD_TOP + 8.1)   # ME6211 on top, over the module, near its 3V3 pin
BL_POS = (W - 7.5, KEYS_Y0 + 32.2)          # backlight MOSFET + LED resistors (right strip)
USB_C_X = W / 2
USB_WALL_T = 0.6
USB_FP_FACE = 3.7
USB_H = 3.16
USB_Z = Z_BP_TOP + USB_H / 2
USB_OPEN = (9.4, 3.8)
USB_FACE_Y = L - USB_WALL_T - 0.1
USB_FP_ORIGIN = (USB_C_X, USB_FACE_Y - USB_FP_FACE)
USB_TAB = (USB_C_X - 6.0, USB_C_X + 6.0, USB_FACE_Y - 0.6)

# Flat back (2026-10-09): the back plate is a flat plate with only the board's
# supports on it, so the whole space between the plate and the board
# (z BACK_T..Z_BP_BOT) is open for the underside parts and the cell. The board
# rests on rails under its side edges (under the screen, from the top end), a
# standoff round every screw, and a pillar under each key switch. There's no
# ledge along its top edge: that length goes to the cell (a 405085 fits).
BP_LIP_IN = WALL + 1.45          # inner edge of the back plate's locating lip
RAIL_W = 1.3                     # side rails: from the lip to 1.15 mm under the board edge
PILLAR_D = 3.0                   # pillars under the key switches
# Battery pads on the underside, just below the screen on the left (BAT+, BAT-);
# fixed by the ordered board, so they're written out here
BAT_PADS = [(12.0, 92.46), (16.0, 92.46)]
# Where the cell may go (shell coords x0, y0, x1, y1): between the rails, from
# the lip at the top end down to just above the battery pads' solder joints.
# The cell sits at the top end, as far from the antenna as it goes; its leads
# run down to the pads.
BATT_BAY = (BP_LIP_IN + RAIL_W, BP_LIP_IN, W - BP_LIP_IN - RAIL_W, BAT_PADS[0][1] - 2.3)
BATT_C = ((BATT_BAY[0] + BATT_BAY[2]) / 2, BATT_BAY[1] + 0.4 + BATT[1] / 2)
RAILS = [(BP_LIP_IN, BP_LIP_IN, BATT_BAY[0], BATT_BAY[3]),                 # left
         (BATT_BAY[2], BP_LIP_IN, W - BP_LIP_IN, BATT_BAY[3])]             # right
# Room the parts on the board's underside need (x0, y0, x1, y1, height below
# the board): nothing on the back plate may reach into these
MOD_POCKET = (MOD_C[0] - MOD_L / 2 - 0.6, MOD_TOP - 0.6, W - BP_INSET + 0.2,
              MOD_TOP + MOD_W + 0.6, MOD_T + 0.4)
UNDERSIDE_ZONES = [
    MOD_POCKET,
    (MOTOR_C[0] - MOTOR_D / 2 - 0.4, MOTOR_C[1] - MOTOR_D / 2 - 0.4,
     MOTOR_C[0] + MOTOR_D / 2 + 0.4, MOTOR_C[1] + MOTOR_D / 2 + 0.4, MOTOR_T + 0.3),
    (MOTOR_C[0] - 3.2, MOTOR_C[1], MOTOR_C[0] + 3.2, MOTOR_PADS_Y + 1.8, 1.5),   # its leads + solder joints
    (BAT_PADS[0][0] - 2.0, BATT_BAY[3] - 0.1, BAT_PADS[1][0] + 2.0, BAT_PADS[0][1] + 1.6, 1.5),
    (USB_C_X - 5.8, USB_FACE_Y - USB_FP_FACE - 5.1, USB_C_X + 5.8, USB_FACE_Y - USB_FP_FACE + 2.4, 2.0),
]
# Standoffs round the back plate's screws, from the plate up to the board (x, y,
# diameter). The board screws' heads hang free under the board, with room kept
# round them (x, y, diameter) that no support on the plate may take.
STANDOFFS = [(x, y, BOSS_D) for x, y in PLATE_SCREWS]
HEAD_ROOM = [(x, y, BOARD_HEAD[0] + 1.0) for x, y in BOARD_SCREWS]


def _pillars():
    """A pillar under each key switch, nudged (up to 1.5 mm, still under the
    switch body) clear of the underside parts, the reset slot, the standoffs,
    the board screws' heads and the cell. A switch over the ESP32 module needs
    none: the module carries it."""
    en = (EN_SLOT[0] - EN_SLOT[2] / 2, EN_SLOT[1] - EN_SLOT[3] / 2,
          EN_SLOT[0] + EN_SLOT[2] / 2, EN_SLOT[1] + EN_SLOT[3] / 2)
    blocked = [z[:4] for z in UNDERSIDE_ZONES] + [en, BATT_BAY]
    r = PILLAR_D / 2 + 0.5

    def clear(x, y):
        box = (x - r, y - r, x + r, y + r)
        return (not any(_overlap(box, b) for b in blocked)
                and all(math.hypot(x - sx, y - sy) > d / 2 + r for sx, sy, d in STANDOFFS + HEAD_ROOM))

    nudges = sorted({(dx * 0.1, dy * 0.1) for dx in range(-15, 16) for dy in range(-15, 16)
                     if math.hypot(dx, dy) <= 15}, key=lambda d: math.hypot(*d))
    out, skipped = [], []
    for name, (x, y) in [(k[0], key_to_shell(k[1])) for k in KEYS] + [("PWR", PWR_KEY)]:
        if MOD_POCKET[0] < x < MOD_POCKET[2] and MOD_POCKET[1] < y < MOD_POCKET[3]:
            continue
        p = next(((round(x + dx, 2), round(y + dy, 2)) for dx, dy in nudges if clear(x + dx, y + dy)), None)
        if p:
            out.append((p[0], p[1], PILLAR_D))
        else:
            skipped.append(name)
    return out, skipped


def _overlap(a, b):
    return a[0] < b[2] and b[0] < a[2] and a[1] < b[3] and b[1] < a[3]


def key_to_shell(p):
    return (KEYS_X0 + p[0], KEYS_Y0 + p[1])


PILLARS, PILLARS_SKIPPED = _pillars()


def bp_outline_contains(x, y, margin=0.0):
    return _rounded_rect_contains(x, y, BP_INSET, BP_INSET, W - BP_INSET, L - BP_INSET,
                                  R_TOP - BP_INSET, R_BOT - BP_INSET, margin)


def _rounded_rect_contains(px, py, x0, y0, x1, y1, r_top, r_bot, margin=0.0):
    x0 += margin; y0 += margin; x1 -= margin; y1 -= margin
    r_top = max(r_top - margin, 0); r_bot = max(r_bot - margin, 0)
    if not (x0 <= px <= x1 and y0 <= py <= y1):
        return False
    for cx, cy, r, sy in ((x0 + r_top, y0 + r_top, r_top, -1), (x1 - r_top, y0 + r_top, r_top, -1),
                          (x0 + r_bot, y1 - r_bot, r_bot, 1), (x1 - r_bot, y1 - r_bot, r_bot, 1)):
        in_corner_x = (px < cx) if cx < (x0 + x1) / 2 else (px > cx)
        in_corner_y = (py < cy) if sy < 0 else (py > cy)
        if in_corner_x and in_corner_y and math.hypot(px - cx, py - cy) > r:
            return False
    return True
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

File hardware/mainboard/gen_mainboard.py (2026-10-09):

"""Main board generator for the Bleep remote, v1 (KiCad 10).

One board carries everything:
  top side, JLCPCB Economic assembly: 14 key switches, USB-C, TP4056 charger,
      ME6211 3.3 V LDO, DRV2605L haptics driver, MMA8452Q accelerometer,
      two side-view IR LEDs + driver, backlight driver, passives
      and a 50-pin 0.5 mm ZIF connector under the panel: the display's FPC
      (BuyDisplay ER-TFT035IPS-6 + touch) folds back under the LCD into it
  underside, you solder: ESP32-S3-WROOM-1-N8R2 (across the board below the
      screen, antenna at the right edge), battery leads, vibration-motor leads

Routing goes through Freerouting (build.sh runs these):
  1. KiCad Python:  gen_mainboard.py place   -> mainboard_placed.kicad_pcb + route_job.json
  2. KiCad Python:  gen_mainboard.py dsn     -> mainboard.dsn (placed board + the
                    hand-drawn pieces as fixed copper, net classes, keep-outs)
  3. freerouting-cli -de mainboard.dsn -do mainboard.ses
  4. KiCad Python:  gen_mainboard.py ses     -> mainboard.kicad_pcb + fab/ BOM and CPL
The older grid router (route.py, then `finish`) still works from route_job.json.
"""

import csv
import json
import math
import os
import re
import sys

import pcbnew

HERE = os.path.dirname(os.path.abspath(__file__))
NL = chr(10)
sys.path.insert(0, os.path.dirname(HERE))
import layout as LY  # noqa: E402
sys.path.insert(0, HERE)
import logo  # noqa: E402

KICAD_FP = os.environ.get("KICAD10_FOOTPRINT_DIR") or os.path.join(
    os.path.dirname(os.path.dirname(sys.executable)), "share", "kicad", "footprints")
LOCAL_FP = HERE
PLACED = os.path.join(HERE, "mainboard_placed.kicad_pcb")
FINAL = os.path.join(HERE, "mainboard.kicad_pcb")
JOB = os.path.join(HERE, "route_job.json")
ROUTES = os.path.join(HERE, "routes.json")
FR_BOARD = os.path.join(HERE, "mainboard_fr.kicad_pcb")
FR_FIXED = os.path.join(HERE, "fr_fixed.json")
DSN = os.path.join(HERE, "mainboard.dsn")
SES = os.path.join(HERE, "mainboard.ses")

# ---------------------------------------------------------------- rules (JLCPCB standard 2-layer)
CLR = 0.13
W_SIG = 0.15
W_PWR = 0.3
W_BAT = 0.6          # the cell -> VSYS -> LDO path (500 mA Wi-Fi bursts on a low cell)
VIA_D, VIA_DRILL = 0.6, 0.3
EDGE_CLR = 0.4
POWER_NETS = ("GND", "3V3", "VBAT", "VSYS", "VBUS", "LED_K", "LED1_A", "LED2_A", "MOT_P", "MOT_N", "BL_A", "BL_K")

# ---------------------------------------------------------------- parts
# value, footprint (lib, name), LCSC part, JLCPCB places it (False = you solder it / no part)
# LCSC numbers checked in the JLCPCB / LCSC catalogues on 2026-10-06.
PARTS = {
    "SW":    ("TS-1187A-B-A-B", LY.SW_FOOTPRINT, "C318884", True),                                   # Basic
    "MOD":   ("ESP32-S3-WROOM-1-N8R2", ("RF_Module", "ESP32-S3-WROOM-1"), "C2913204", False),        # LCSC, you solder
    "CHG":   ("TP4056", ("Package_SO", "SOIC-8-1EP_3.9x4.9mm_P1.27mm_EP2.41x3.3mm"), "C16581", True),  # Extended
    "LDO":   ("ME6211C33M5G-N", ("Package_TO_SOT_SMD", "SOT-23-5"), "C82942", True),                  # Extended
    "DRV":   ("DRV2605LDGST", ("Package_SO", "MSOP-10_3x3mm_P0.5mm"), "C425927", True),               # Extended
    "ACC":   ("MMA8452QR1", ("remote", "MMA8452Q_QFN-16_3x3mm_P0.5mm"), "C11360", True),           # Extended (the LGA LIS2DH12 is Standard-only)
    "Q":     ("AO3400A", ("Package_TO_SOT_SMD", "SOT-23"), "C20917", True),                             # Basic
    "QP":    ("AO3401A", ("Package_TO_SOT_SMD", "SOT-23"), "C15127", True),                             # Basic
    "SCH":   ("B5819W", ("Diode_SMD", "D_SOD-123"), "C8598", True),                                    # Basic
    "USB":   ("TYPE-C 16PIN 2MD(073)", ("Connector_USB", "USB_C_Receptacle_HRO_TYPE-C-31-M-12"), "C2765186", True),  # Extended
    "LED":   ("VSMB2948SL", ("remote", "VSMB2948SL_SideView"), "C6604342", True),                     # Extended
    "ZIF":   ("FPC-05F-50PH15", ("remote", "FPC-05F-50PH15"), "C2856826", True),                   # Extended
    "R10":   ("10R", ("Resistor_SMD", "R_0603_1608Metric"), "C22859", True),
    "R22":   ("22R", ("Resistor_SMD", "R_0603_1608Metric"), "C23345", True),
    "R22P":  ("22R", ("Resistor_SMD", "R_1206_3216Metric"), "C17958", True),                    # Basic, 250 mW
    "R100":  ("100R", ("Resistor_SMD", "R_0603_1608Metric"), "C22775", True),
    "R220":  ("220R", ("Resistor_SMD", "R_0603_1608Metric"), "C22962", True),
    "R3k3":  ("3.3k", ("Resistor_SMD", "R_0603_1608Metric"), "C22978", True),
    "R4k7":  ("4.7k", ("Resistor_SMD", "R_0603_1608Metric"), "C23162", True),
    "R5k1":  ("5.1k", ("Resistor_SMD", "R_0603_1608Metric"), "C23186", True),
    "R10k":  ("10k", ("Resistor_SMD", "R_0603_1608Metric"), "C25804", True),
    "R100k": ("100k", ("Resistor_SMD", "R_0603_1608Metric"), "C25803", True),
    "C100n": ("100nF", ("Capacitor_SMD", "C_0603_1608Metric"), "C14663", True),
    "C1u":   ("1uF", ("Capacitor_SMD", "C_0603_1608Metric"), "C15849", True),
    "C10u":  ("10uF", ("Capacitor_SMD", "C_0805_2012Metric"), "C15850", True),
    "C10uS": ("10uF", ("Capacitor_SMD", "C_0603_1608Metric"), "C19702", True),                 # Basic, 0.9 mm high
    "C22u":  ("22uF", ("Capacitor_SMD", "C_0805_2012Metric"), "C45783", True),
    "IRRX":  ("IRM-H638T/TR2", ("remote", "IRM-H638T"), "C91447", True),                           # Extended
    "ALS":   ("LTR-303ALS-01", ("remote", "LTR-303ALS-01"), "C364577", True),                      # Extended
    "FG":    ("MAX17048G+T10", ("remote", "MAX17048_TDFN-8_2x2mm"), "C2682616", True),             # Extended
    "BATP":  ("battery lead pad", ("TestPoint", "TestPoint_Pad_2.0x2.0mm"), "", False),
    "ENP":   ("reset pad", ("TestPoint", "TestPoint_Pad_1.5x1.5mm"), "", False),
    "LRA":   ("LRA 0832 (8 mm coin, wired)", ("remote", "LRA_8mm_WirePads"), "", False),
    "HOLE":  ("M2", ("MountingHole", "MountingHole_2.2mm_M2"), "", False),
}

# ESP32-S3-WROOM-1 pin numbers (datasheet / LCSC symbol C2913204)
WROOM = {"GND": [1, 40, 41], "3V3": [2], "EN": [3], "IO4": [4], "IO5": [5], "IO6": [6], "IO7": [7],
         "IO15": [8], "IO16": [9], "IO17": [10], "IO18": [11], "IO8": [12], "IO19": [13], "IO20": [14],
         "IO3": [15], "IO46": [16], "IO9": [17], "IO10": [18], "IO11": [19], "IO12": [20], "IO13": [21],
         "IO14": [22], "IO21": [23], "IO47": [24], "IO48": [25], "IO45": [26], "IO0": [27], "IO35": [28],
         "IO36": [29], "IO37": [30], "IO38": [31], "IO39": [32], "IO40": [33], "IO41": [34], "IO42": [35],
         "IO44": [36], "IO43": [37], "IO2": [38], "IO1": [39]}
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

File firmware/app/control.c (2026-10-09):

#include "control.h"

#include <stdio.h>
#include <string.h>
#include "app.h"
#include "ha.h"
#include "hal.h"
#include "radio.h"

void control_select_device(int dev)
{
    if (dev >= g_model.n_devices) dev = -1;
    if (g_model.active_dev == dev) return;
    g_model.active_dev = dev;
    if (dev >= 0) hal_log("device: %s selected", g_model.devices[dev].name);
    radio_update();
    app_notify(EV_ACTIVITY, g_model.running);
}

const char *control_target_name(const char **icon)
{
    if (g_model.active_dev >= 0) {
        const device_t *d = &g_model.devices[g_model.active_dev];
        if (icon) *icon = dev_kind_icon(d->kind);
        return d->name;
    }
    if (g_model.running >= 0) {
        const activity_t *a = &g_model.activities[g_model.running];
        if (icon) *icon = activity_icon(a);
        return a->name;
    }
    return NULL;
}

/* ---- sending ---- */

static void send_ha(const device_t *d, fn_t fn)
{
    int e = ha_find(d->ha_entity);
    if (e < 0) {
        hal_log("ha: %s not found", d->ha_entity);
        return;
    }
    ha_entity_t *ent = ha_get(e);
    switch (fn) {
    case FN_POWER: ha_action(e, ent->on ? "turn_off" : "turn_on"); break;
    case FN_POWER_ON: ha_action(e, "turn_on"); break;
    case FN_POWER_OFF: ha_action(e, "turn_off"); break;
    case FN_PLAY_PAUSE: ha_action(e, "media_play_pause"); break;
    case FN_VOL_UP: ha_set_value(e, ent->value + 2); break;
    case FN_VOL_DOWN: ha_set_value(e, ent->value - 2); break;
    case FN_MUTE: ha_action(e, "volume_mute"); break;
    case FN_FWD: ha_action(e, "media_next_track"); break;
    case FN_REW: ha_action(e, "media_previous_track"); break;
    default: {
        /* navigation goes through remote.send_command on the matching remote entity */
        hal_log("ha: remote.send_command %s -> %s", fn_name(fn), d->ha_entity);
        break;
    }
    }
}

/* ---- sending: a press (down) and its release (up) ---- */

#define IR_TAP (-2)             /* ir_owner for a one-off send, not a held key */
static int ir_owner = -1;       /* the key whose IR code the HAL is repeating */

static void bookkeep(device_t *d, fn_t fn)
{
    if (fn == FN_POWER) d->on = !d->on;
    if (fn == FN_POWER_ON) d->on = true;
    if (fn == FN_POWER_OFF) d->on = false;
    if (fn >= FN_INPUT_1 && fn <= FN_INPUT_4) d->input = fn - FN_INPUT_1 + 1;
}

/* owner: the key holding it, or IR_TAP. False if the device hasn't got fn. */
static bool code_down(int dev, fn_t fn, int owner)
{
    if (dev < 0 || dev >= g_model.n_devices) return false;
    device_t *d = &g_model.devices[dev];
    code_t c = d->fn[fn];
    switch (c.transport) {
    case TR_IR:
        hal_ir_start(c.proto, c.a, c.b);
        ir_owner = owner;
        break;
    case TR_BLE:
        radio_ble_key(dev, c.a, c.b, true);
        break;
    case TR_HA:
        send_ha(d, fn);
        break;
    default:
        hal_log("%s has no %s", d->name, fn_name(fn));
        return false;
    }
    bookkeep(d, fn);
    return true;
}

static void code_up(int dev, fn_t fn, int owner)
{
    if (dev < 0 || dev >= g_model.n_devices) return;
    code_t c = g_model.devices[dev].fn[fn];
    if (c.transport == TR_IR && ir_owner == owner) {
        hal_ir_stop();   /* not if another key or a tap has taken the LED since */
        ir_owner = -1;
    } else if (c.transport == TR_BLE) {
        radio_ble_key(dev, c.a, c.b, false);
    }
}

void ir_send_once(const code_t *c)
{
    hal_ir_start(c->proto, c->a, c->b);
    hal_ir_stop();
    ir_owner = -1;
}

bool device_send(int dev, fn_t fn)
{
    if (!device_send_quiet(dev, fn)) {
        app_buzz(HAPTIC_NO);
        return false;
    }
    /* send first, then buzz: the haptic driver and Wi-Fi share the LDO */
    app_buzz(HAPTIC_TICK);
    return true;
}

bool device_send_quiet(int dev, fn_t fn)
{
    if (!code_down(dev, fn, IR_TAP)) return false;
    code_up(dev, fn, IR_TAP);
    return true;
}

/* ---- keys ---- */

static struct {
    bool down;
    int8_t dev;
    uint8_t fn;
    uint32_t next;              /* next repeat */
} held[KEY_COUNT];
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

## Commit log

2026-10-09 Bleep v1: touch remote hardware (main board as ordered, shell, viewer, brand)
    Main board v1 is locked: these are the files ordered from JLCPCB on
    2026-10-08. The shell is set up for a 4 mm flat Li-Po (12.95 mm thick).
    See HANDOFF.md for the current state and open work.
    [back_plate.stl, caps.stl, caps_labels.stl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]
2026-10-09 Flat back plate with room for a 405085 cell
    The back plate is now flat: the support platform and its pockets are
    gone, so the 4.5 mm under the main board is open. The board rests on
    side rails under the screen, a standoff at each screw and a 3 mm pillar
    under each key switch. Dropping the top ledge lets cells up to
    4.0 x 50.8 x 86.1 mm fit under the screen; BATT is set to a 405085.
    The shell stays 12.95 mm thick and no locked board value moves.
    build.sh now runs on Linux (tools from PATH, PNG renders skipped with
    no display) and packs viewer meshes without trimesh. README, HANDOFF
    and the memory copy are updated; README screws corrected to M2x8.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
    [back_plate.stl, params.scad, remote.scad]
2026-10-09 Shell: screws, separate window prints, blue windows in the design
    - The board screws to the four key-area posts (4 x M2x4 from its underside);
    the back plate keeps only the 2 bottom M2x8 screws plus its snap fingers.
    - IR and light-sensor windows are now two separate translucent PETG prints
    (ir_window.stl, sensor_window.stl) instead of the multi-material inlay.
    - Viewer, logo outlines and the concept page show the blue windows.
    - Design: the "Bleep Remote UI" mock-up the firmware UI is built from.
    [back_plate.stl, caps.stl, fit_test_keys.stl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]
2026-10-09 Firmware: app and UI in a PC/browser emulator, with scripted tests
    The firmware's portable app (C) and LVGL 9 UI, built from the Bleep Remote UI
    design, running against a HAL that the emulator implements; the ESP32-S3
    port implements the same hal/hal.h when the boards arrive.
    - Activities (Create/Update editor, icons, start sequences, key routing),
    routines (device buttons, Home Assistant actions, activities; waits;
    progress window with Stop), devices (Bluetooth pairing, IR library and
    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
    [config_compat.txt, config_v1.txt]
2026-10-09 Firmware: HAL reshaped for the real board (wake = reboot, held keys, real links)
    - Deep sleep is a reboot: a 1 KB RTC block (app/retained.c) keeps the
    running activity, devices switched on, the page and each key's code; a
    key that wakes the remote goes out over IR before boot (app_early).
    The emulator reboots for real too (sim/boot.c: new process, execv, or a
    page reload in the browser).
    - Wake mask and wake-loop guard: held keys can't wake it; three idle touch
    or lift wakes in a row disarm that source until a key wakes it.
    - Held keys: IR start/stop with protocol repeats, Bluetooth key down/up,
    Home Assistant volume and D-pad repeats. IR: Kaseikyo, SIRC15, SIRC20.
    - Links from H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
    [app.c, boot.c, config.c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]
